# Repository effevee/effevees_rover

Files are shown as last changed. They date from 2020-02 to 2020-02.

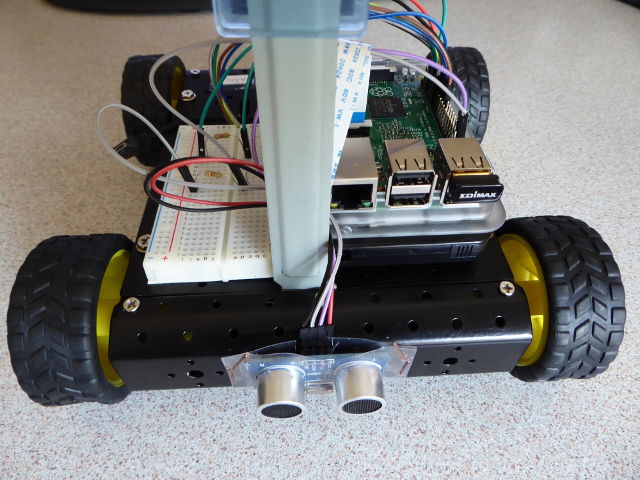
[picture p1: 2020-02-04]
documentatie/rover07.jpg

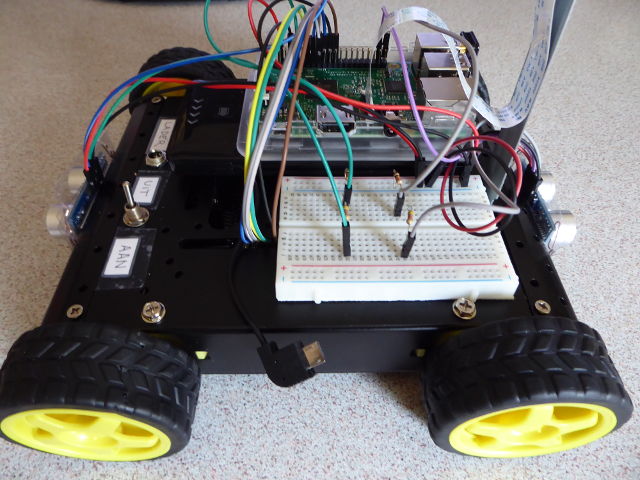
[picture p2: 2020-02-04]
documentatie/rover06.jpg

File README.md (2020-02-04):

# effevees_rover
Effevee's rover is een robotvoertuig dat op afstand bestuurd wordt en ondertussen beelden streamt van de onboard Pi camera. De aanwezige afstandssensoren zorgt ervoor dat botsingen met obstakels worden vermeden. De stuursoftware is geschreven in python en wordt bediend via een web interface. De Raspberry Pi is voorzien van een wifi module zodat we vanaf iedere pc, tablet of smartphone met een verbinding op het netwerk het voertuig draadloos kunnen besturen. In principe kan je zelfs via port forwarding op je router het voertuig besturen over het internet. Als uitbreiding
is er ook een autonavigatie modus van het robotvoertuig toegevoegd.

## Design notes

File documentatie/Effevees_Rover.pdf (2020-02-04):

# Eindproef cursus Raspberry Pi :

# Effevee's Rover

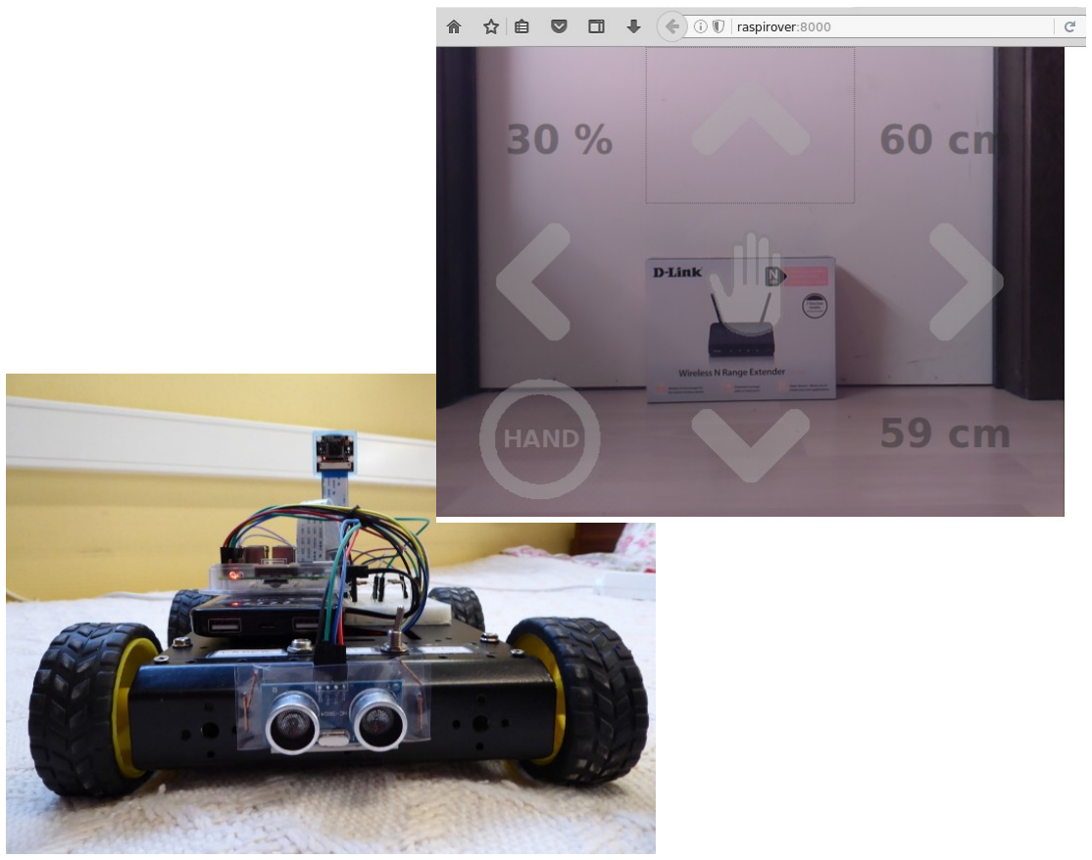
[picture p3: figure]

Alle documentatie en code van dit project kan je hier (https://drive.google.com/folderview?id=0B_sqxi1cT7K0WTJnMkV1VVNwUnM&usp=sharing) downloaden. De code is ruim voorzien van commentaar en uitleg. Mocht je nog met vragen zitten, stuur dan gerust een email naar effevee AT gmail DOT com.

Enjoy,

Effevee.

©2016 Frank Vergote | Pag 1 | Effevee's Rover

## Inhoudsopgave

©2016 Frank Vergote | Pag 2 | Effevee's Rover

## Beschrijving

Effevee's rover is een robotvoertuig dat op afstand bestuurd wordt en ondertussen beelden streamt van de onboard Pi camera. De aanwezige afstandssensoren zorgt ervoor dat botsingen met obstakels worden vermeden. De stuursoftware is geschreven in python en wordt bediend via een web interface. De Raspberry Pi is voorzien van een wifi module zodat we vanaf iedere pc, tablet of smartphone met een verbinding op het netwerk het voertuig draadloos kunnen besturen. In principe kan je zelfs via port forwarding op je router het voertuig besturen over het internet. Als uitbreiding is er ook een autonavigatie modus van het robotvoertuig toegevoegd.

## Hardware

### Controller

- Raspberry Pi 2 (http://www.conrad.be/ce/nl/product/1316978/Raspberry-Pi-2-model-B-1-GB-zonder-besturingssysteem) | 44,99 €
- EW-7811Un Edimax Wifi usb module (http://www.conrad.be/ce/nl/product/993655/Raspberry-Pi-WiFi-stick-EDIMAX-EW-7811Un?queryFromSuggest=true) | 9,79 €
- Pi (http://www.sainsmart.com/raspberry-noir-pi-camera-module-board-5mp-webcam-video-1080p-720p.html) NoIR (http://www.sainsmart.com/raspberry-noir-pi-camera-module-board-5mp-webcam-video-1080p-720p.html)camera module (http://www.sainsmart.com/raspberry-noir-pi-camera-module-board-5mp-webcam-video-1080p-720p.html) | 26,73 $
- Medion MD84610 powerbank 5V | 14,99 €

### Robotvoertuig

- 4 (http://www.sainsmart.com/sainsmart-4wd-drive-aluminum-mobile-robot-platform-for-robot-arduino-uno-mega2560-r3-duemilanove-black.html) wiel voertuig (http://www.sainsmart.com/sainsmart-4wd-drive-aluminum-mobile-robot-platform-for-robot-arduino-uno-mega2560-r3-duemilanove-black.html) chassis (http://www.sainsmart.com/sainsmart-4wd-drive-aluminum-mobile-robot-platform-for-robot-arduino-uno-mega2560-r3-duemilanove-black.html) met (http://www.sainsmart.com/sainsmart-4wd-drive-aluminum-mobile-robot-platform-for-robot-arduino-uno-mega2560-r3-duemilanove-black.html)4 gelijkstroommotoren (http://www.sainsmart.com/sainsmart-4wd-drive-aluminum-mobile-robot-platform-for-robot-arduino-uno-mega2560-r3-duemilanove-black.html) | 37,99 $
- motorstuurmodule L298N (http://www.sainsmart.com/sainsmart-l298n-dual-h-bridge-stepper-motor-driver-controller-board-module-for-arduino-robot.html) | 6,88 $
- NiMH 9,6V 1300mAh accupack (http://www.conrad.be/ce/nl/product/206632/NiMH-accupack-96-V-1300-mAh-Conrad-energy-Block-Mini-Tamiya-bus) | 27,99 €
- Voltcraft snellader (http://www.conrad.be/ce/nl/product/237851/VOLTCRAFT-230-V-snellader-1-2-A-voor-NiCd-NiMH-accupacks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) | 24,99 €
- afstandssensor (http://www.sainsmart.com/ultrasonic-ranging-detector-mod-hc-sr04-distance-sensor.html) en (http://www.sainsmart.com/ultrasonic-ranging-detector-mod-hc-sr04-distance-sensor.html) HC-SR04 (http://www.sainsmart.com/ultrasonic-ranging-detector-mod-hc-sr04-distance-sensor.html) | 2x 3,70 $
- klein breadboard (https://www.sossolutions.be/breadbordje-formaat-middel-400-gats) | 7,95 €

### Allerlei

- Digitale multimeter
- Top Craft Soldeerboutset en soldeertin | 9,99 €
- K (http://www.conrad.be/ce/nl/product/068511/Velleman-KMOW-Draad-1-x-020-mm-1-set?queryFromSuggest=true)ableerdraad 0,2 mm² (http://www.conrad.be/ce/nl/product/068511/Velleman-KMOW-Draad-1-x-020-mm-1-set?queryFromSuggest=true) | 9,99 €
- J (http://www.sainsmart.com/40pcs-dupont-wire-jumpercables-21cm-2-54mm-female-to-female-for-arduino.html)umperkabels (http://www.sainsmart.com/40pcs-dupont-wire-jumpercables-21cm-2-54mm-female-to-female-for-arduino.html) v/v en m/v | 2x 1,84 $
- V (http://www.conrad.be/ce/nl/product/419956/TOOLCRAFT-Klittenband-om-vast-te-plakken-Haak-en-lusdeel-Extra-sterk-l-x-b-1000-mm-x-50-mm-Zwart-1-rollen)elcro (http://www.conrad.be/ce/nl/product/419956/TOOLCRAFT-Klittenband-om-vast-te-plakken-Haak-en-lusdeel-Extra-sterk-l-x-b-1000-mm-x-50-mm-Zwart-1-rollen) en/of Tesa bevestigingsband | 3,62 €
- Afstandhouders
- Schroeven en moeren M3
©2016 Frank Vergote | Pag 3 | Effevee's Rover

## Controller

### Raspberry Pi 2

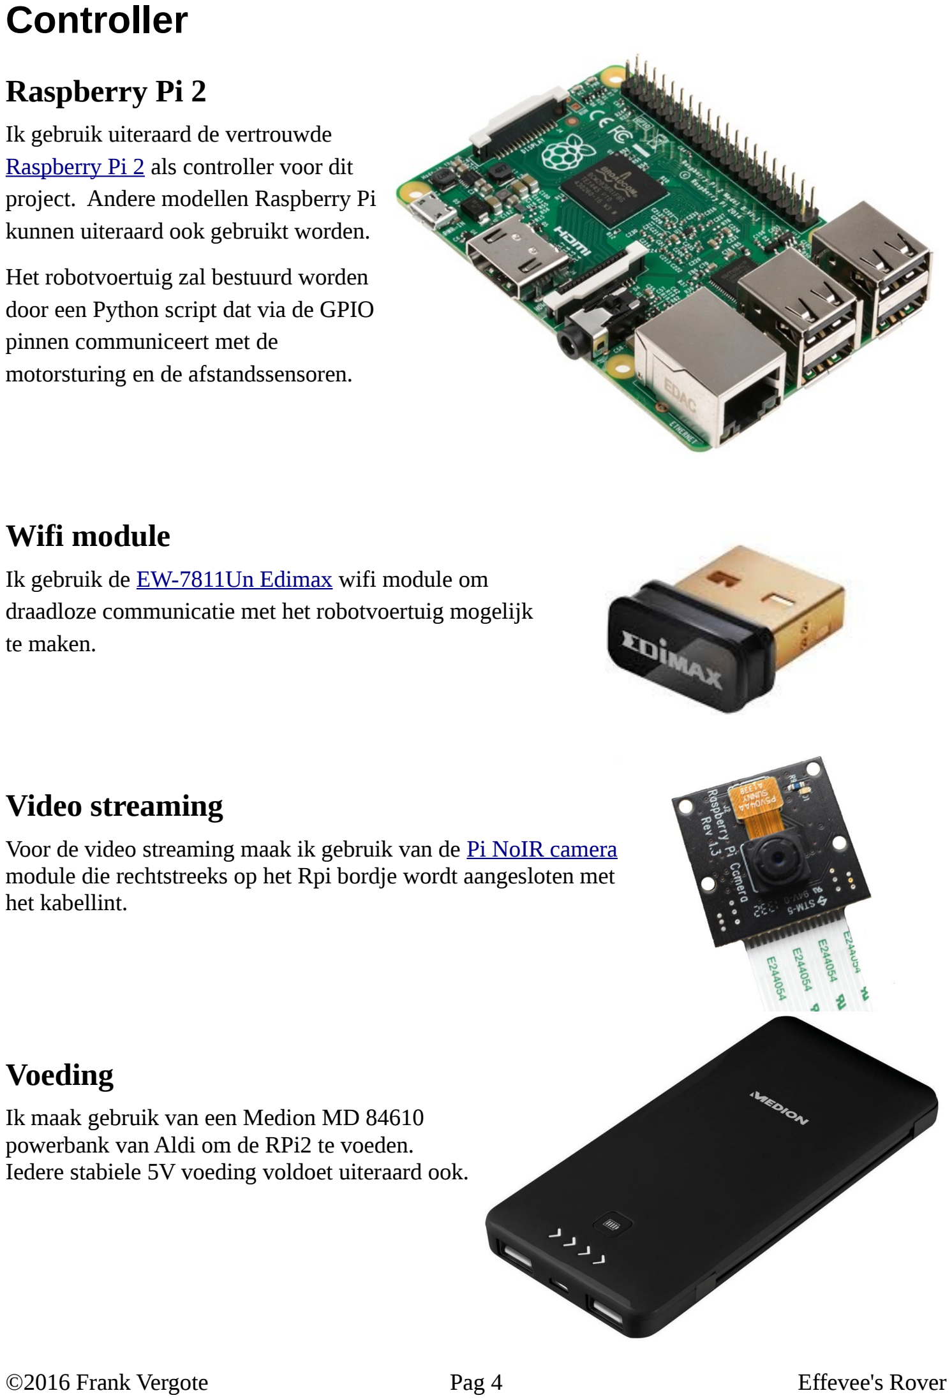
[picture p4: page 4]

Ik gebruik uiteraard de vertrouwde Raspberry Pi 2 (https://www.raspberrypi.org/products/raspberry-pi-2-model-b/) als controller voor dit project. Andere modellen Raspberry Pi kunnen uiteraard ook gebruikt worden. Het robotvoertuig zal bestuurd worden door een Python script dat via de GPIO pinnen communiceert met de motorsturing en de afstandssensoren.

### Wifi module

Ik gebruik de EW-7811Un Edimax (http://www.edimax.com/edimax/merchandise/merchandise_detail/data/edimax/global/wireless_adapters_n150/ew-7811un) wifi module om draadloze communicatie met het robotvoertuig mogelijk te maken.

### Video streaming

Voor de video streaming maak ik gebruik van de Pi NoIR camera (https://www.raspberrypi.org/products/pi-noir-camera/) module die rechtstreeks op het Rpi bordje wordt aangesloten met het kabellint.

### Voeding

Ik maak gebruik van een Medion MD 84610 powerbank van Aldi om de RPi2 te voeden. Iedere stabiele 5V voeding voldoet uiteraard ook.

©2016 Frank Vergote | Pag 4 | Effevee's Rover

## Robotvoertuig

### 4 wiel voertuig chassis

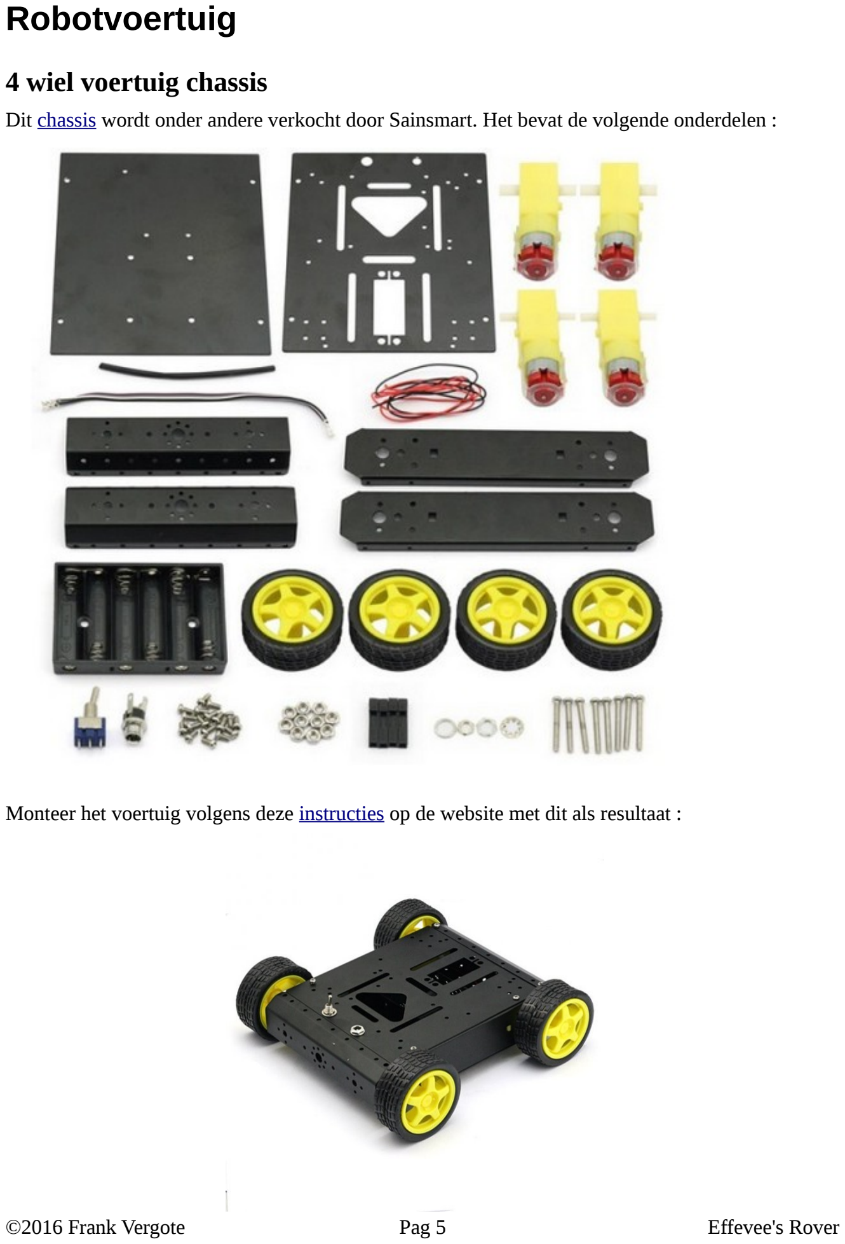
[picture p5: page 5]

Dit chassis (http://www.sainsmart.com/sainsmart-4wd-drive-aluminum-mobile-robot-platform-for-robot-arduino-uno-mega2560-r3-duemilanove-black.html) wordt onder andere verkocht door Sainsmart. Het bevat de volgende onderdelen :

Monteer het voertuig volgens deze instructies (http://www.sainsmart.com/zen/documents/20-011-922/4WD.pdf) op de website met dit als resultaat :

©2016 Frank Vergote | Pag 5 | Effevee's Rover

### Motorsturing

Stuurmodule L298N
Deze module wordt onder andere verkocht door Sainsmart. (http://www.sainsmart.com/sainsmart-l298n-dual-h-bridge-stepper-motor-driver-controller-board-module-for-arduino-robot.html)

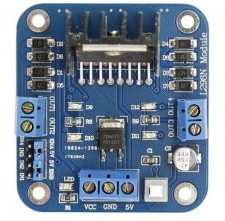
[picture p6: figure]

De L298N (gemonteerd op de grote koelvin) is een zogenaamde H-bridge. Die worden veel gebruikt om motoren aan te sturen.

Deze module kan dienen voor zowel het sturen van 2 stappenmotoren (servomotoren) als van 2 gewone DC motoren. In dit project worden de linker- en rechter DC motoren parallel geschakeld op de module.

Voor het aansturen van een stappenmotor moet de jumper over de enable pin en de 5V pin geplaatst worden.

Voor het aansturen van een DC motor kan je een PWM signaal op de enable pin plaatsen om de draaisnelheid van de motoren aan te passen.

De draairichting van de motoren wordt bepaald door de signalen die op de In aansluitingen staan. De combinatie LAAG – HOOG laat de motor vooruit draaien; de combinatie HOOG – LAAG achteruit; de combinatie LAAG – LAAG stopt de motor.

Wanneer een externe voeding (>5V) is aangesloten op VCC, dan kan je met de 5V aansluiting op de module de Raspberry Pi voeden. Uit praktijktesten is echter gebleken dat deze voeding niet stabiel genoeg is en willekeurige reboots van de Rpi veroorzaakt. We voorzien dus een aparte voeding (Medion Powerbank) voor onze Pi.

L298N aansluitingen

Pin L298N | Functie
Out1 | Motor A aansluiting +
Out2 | Motor A aansluiting -
Out3 | Motor B aansluiting +
Out4 | Motor B aansluiting -
VCC | Voedingsspanning (5V – 35V)
GND | Massa
5V | 5V output als VCC reeds spanning heeft > 5V (niet betrouwbaar)
EnA | Motor A : met jumper = stappenmotor – zonder = DC motor snelheid via PWM
EnB | Motor B : met jumper = stappenmotor – zonder = DC motor snelheid via PWM
In1, In2 | Motor A draairichting : vooruit = LAAG-HOOG / achteruit = HOOG-LAAG
In3, In4 | Motor B draairichting : vooruit = LAAG-HOOG / achteruit = HOOG-LAAG
©2016 Frank Vergote | Pag 6 | Effevee's Rover

### Voeding

Accupack
De voeding die ik voor de aandrijving van de rover gebruik is een 9,6V/1300 mAh NiMH accupack (http://www.conrad.be/ce/nl/product/206632/NiMH-accupack-96-V-1300-mAh-Conrad-energy-Block-Mini-Tamiya-bus/SHOP_AREA_20058) die je onder andere bij Conrad kan aanschaffen.
Deze voor gemonteerde accupack bestaat uit 8 NiMH cellen met een vermogen van 1300 mAh en een spanning van 9,6V. Het geheel is gemonteerd met een mini Tamiya stekker aansluiting.

Snellader

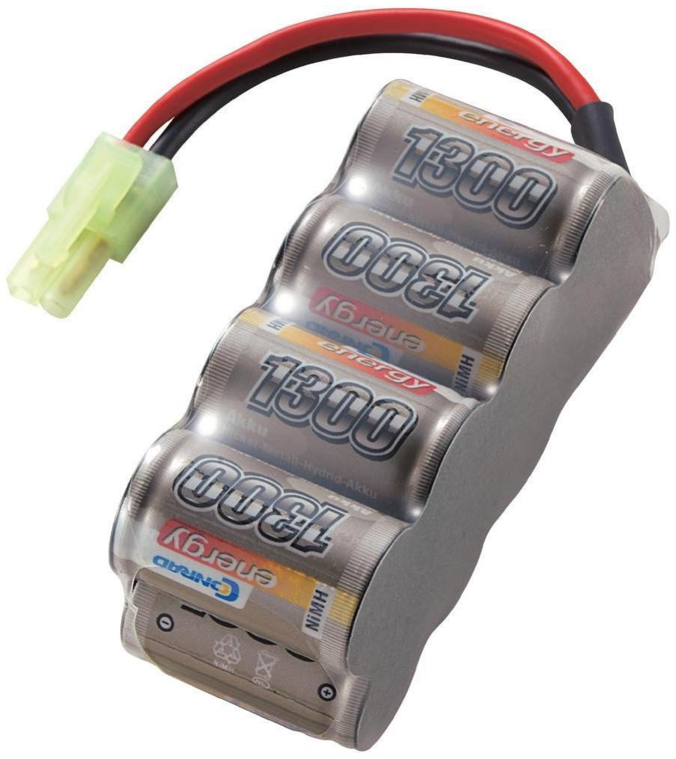
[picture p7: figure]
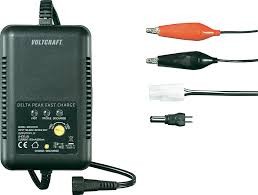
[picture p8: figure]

Ik heb er ook een Volcraft 230V snellader (http://www.conrad.be/ce/nl/product/237851/VOLTCRAFT-230-V-snellader-1-2-A-voor-NiCd-NiMH-accupacks/SHOP_AREA_21100) bijgekocht. Deze is geschikt voor NiCd en NiMH accupacks van 5 tot 8 cellen met een maximum vermogen tot 4300 mAh en heeft een instelbare laadstroom van 1A of 2A.
Dit is de ideale snellader voor racingpacks met Tamiya-stekkers. De betrouwbare Delta-V-uitschakeling garandeert een maximum lading zonder dat de accu wordt overladen. De laadtoestand wordt mbv 3 LED's aangegeven.

### Afstandssensoren

Afstandssensor HC-SR04
De HC-SR04 (http://www.sainsmart.com/ultrasonic-ranging-detector-mod-hc-sr04-distance-sensor.html) kan je onder andere kopen bij Sainsmart.
De sensor werkt volgens hetzelfde principe als de sonar van een duikboot. De sensor heeft een bereik van 2 tot 400 cm.
De Trigger pin wordt gedurende minstens 10 µs
hoog gezet. Hierdoor worden 8 ultrasone
geluidsignalen van 40 kHz uitgezonden vanaf de

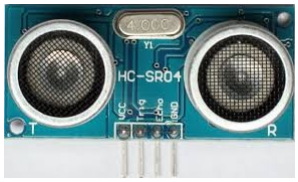
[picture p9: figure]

linker sensor (T van Transmit) die werkt als een mini luidspreker. De geluidsignalen worden door obstakels gedeeltelijk teruggekaatst en opgevangen door de rechter sensor (R van Recieve). Hierdoor wordt de Echo pin een tijd hoog evenredig met de afstand tot het obstakel. Geluidsignalen hebben een snelheid van 340 m/s in lucht. De tijd dat de echo puls hoog is, is equivalent met 2 x de afstand tot het obstakel. De formule om de afstand te berekenen wordt dus : Afstand (in cm) = Snelheid (34000 cm/s) x Echo tijd (in s) / 2

©2016 Frank Vergote | Pag 7 | Effevee's Rover

HC-SR04 aansluitingen

Pin HC-SR04 | Functie
VCC | Voeding +5V
Trigger | Output
Echo | Input
GND | Voeding -

### Robotvoertuig

Schakeling
We verbinden de verschillende onderdelen als volgt met elkaar :
Van | Jumper | Naar
Onderdeel | Pin | kleur | Onderdeel | GPIO | Fysiek#
L298N stuurmodule | OUT1 | zwart | Motoren links | | -
| OUT2 | geel/rood | | | +
| OUT3 | groen/blauw | Motoren rechts | | +
| OUT4 | zwart | | | -
| VCC | rood | Accu 9,6V | | +
| GND | zwart | | | -
| | zwart | Breadboard -
| IN1 | groen | RPi2 | 17 | 11
| IN2 | geel | | 18 | 12
| IN3 | wit | | 22 | 15
| IN4 | grijs | | 23 | 16
| ENA | blauw | | 24 | 18
| ENB | bruin | | 25 | 22
Breadboard | - zwart | | RPi2 | GND | 6
| + | rood | | 5V | 2
HC-SR04 Voor | VCC | rood | Breadboard +
| Trig | blauw | RPi2 | 27 | 13
| Echo [°] | groen | | 4 | 7
| GND | zwart | Breadboard -
HC-SR04 Achter | VCC | rood | Breadboard +
| Trig | purper | RPi2 | 20 | 38
| Echo[°] | grijs | | 21 | 40
| GND | zwart | Breadboard -
©2016 Frank Vergote | Pag 8 | Effevee's Rover

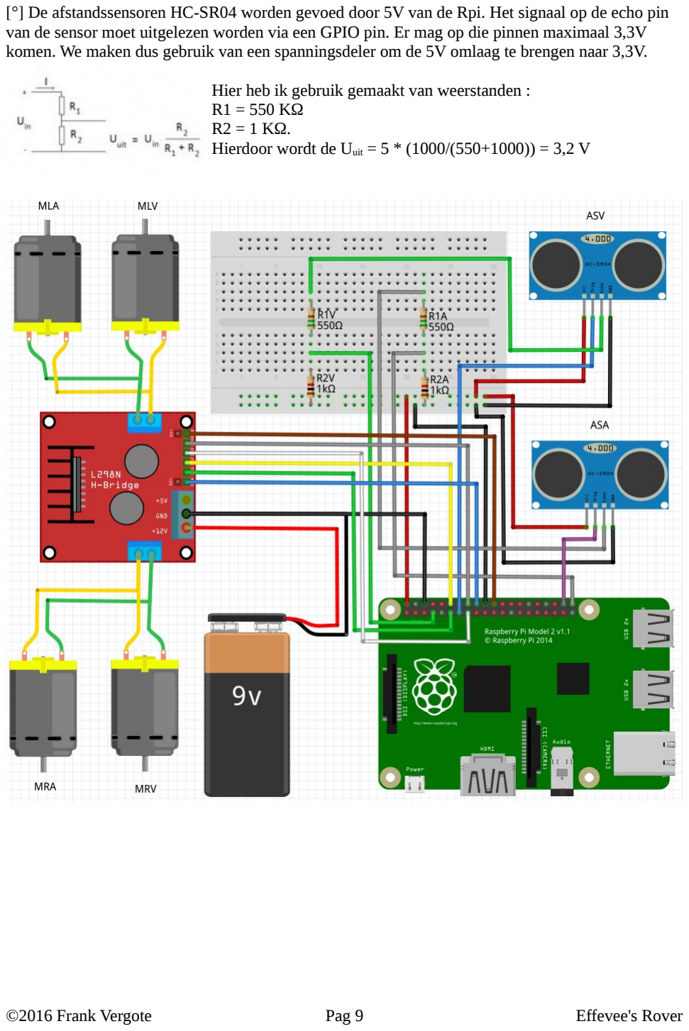
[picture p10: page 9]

[°] De afstandssensoren HC-SR04 worden gevoed door 5V van de Rpi. Het signaal op de echo pin van de sensor moet uitgelezen worden via een GPIO pin. Er mag op die pinnen maximaal 3,3V komen. We maken dus gebruik van een spanningsdeler om de 5V omlaag te brengen naar 3,3V.

Hier heb ik gebruik gemaakt van weerstanden :
R1 = 550 KΩ
R2 = 1 KΩ.
Hierdoor wordt de Uuit = 5 * (1000/(550+1000)) = 3,2 V
©2016 Frank Vergote | Pag 9 | Effevee's Rover

Montage

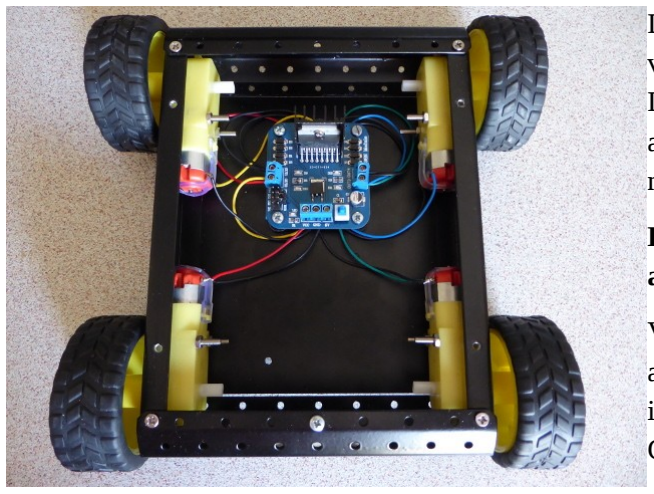
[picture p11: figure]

De L298N stuurmodule is op de onderplaat van het robotvoertuig chassis gemonteerd. De linker motoren zijn verbonden met de aansluitingen OUT1 en OUT2; de rechter motoren met OUT3 en OUT4.
Let op met de polariteit van de aansluitingen !
Verbind 6 jumper kabels met de andere aansluitingen van de L298N. Die verbind ik straks doorheen de bovenplaat met de GPIO pinnen van de Rpi.

De aan/uit schakelaar en de connector voor

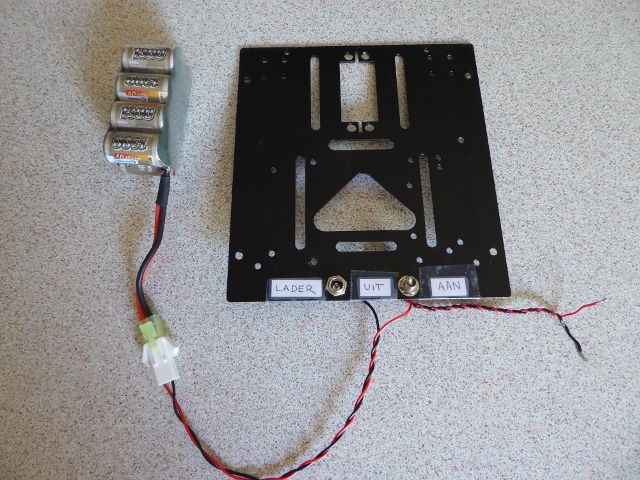
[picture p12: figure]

de lader zijn in de bovenplaat gemonteerd. Sluit de rode kabel aan op VCC en de zwarte op GND van de L298N stuurmodule.
Sluit ook een zwarte jumper kabel aan op GND . Die verbind ik straks met GND op de Rpi om een gesloten kring te maken. Sluit de Tamiya stekker aan op de accupack en bevestig deze met velcro in het chassis.

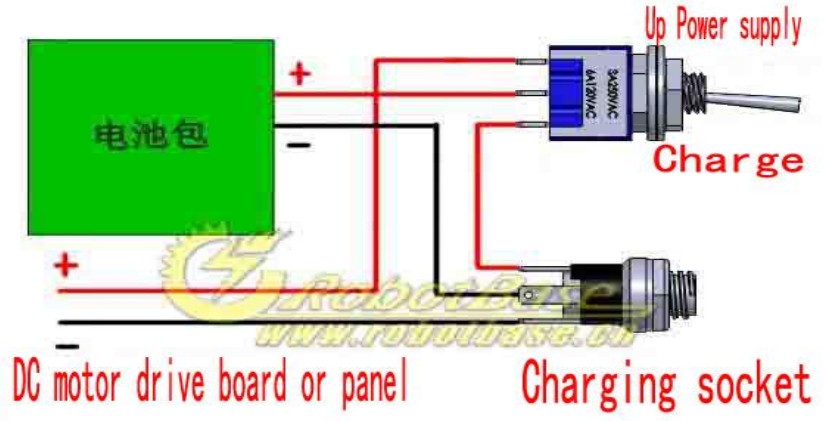
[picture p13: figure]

Dit is het bedradingsschema voor de verbinding van accupack, aan/uit schakelaar, oplaadconnector en L298N stuurmodule.
Test alles grondig na met je digitale multimeter vooraleer je de accupack en de stuurmodule aansluit.
©2016 Frank Vergote | Pag 10 | Effevee's Rover

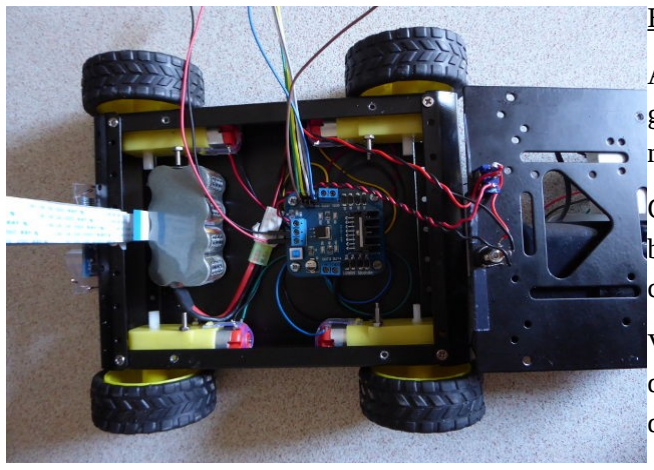
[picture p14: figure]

Binnenzicht :
Alle aansluitingen met de L298N zijn gemaakt en de jumper kabels voor de motorsturing zijn geplaatst.
Geleid de jumper kabels doorheen de bovenplaat en schroef deze vast op het chassis.
Verbind de jumper kabels van de L298N en de HC-SR04 sensoren met de Rpi volgens de schakeling tabel.

Vooraanzicht :

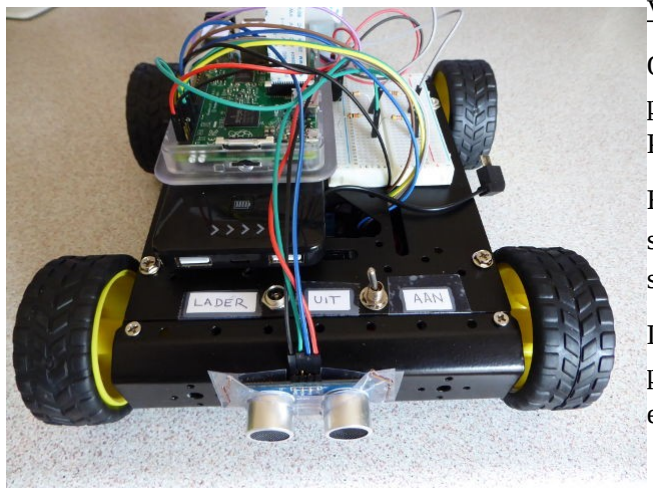
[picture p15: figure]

Op de bovenplaat heb ik links de Medion powerbank met daar bovenop de Raspberry Pi bevestigd.
Rechts is een klein breadboard voor de spanningsdelers van de HC-SR04 afstand sensoren.
De HC-SR04 heb ik met een stuk harde plastic en Tesa band bevestigd op de voor-en achterzijde van de chassis.

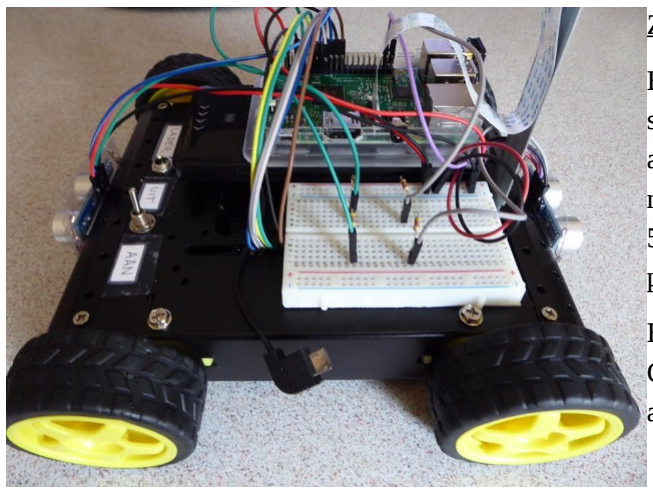
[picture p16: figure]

Zijaanzicht :
Hier zie je beter het breadboard met de spanningsdelers van de voorste en achterste afstand sensoren. De spanningsdelers zijn nodig omdat de HC-SR04 enkel werken op 5V en de Rpi maximaal 3,3V op zijn gpio pinnen mag krijgen.
Bemerk ook de lint connector van de Pi Camera die rechtstreeks op de Rpi is aangesloten.
©2016 Frank Vergote | Pag 11 | Effevee's Rover

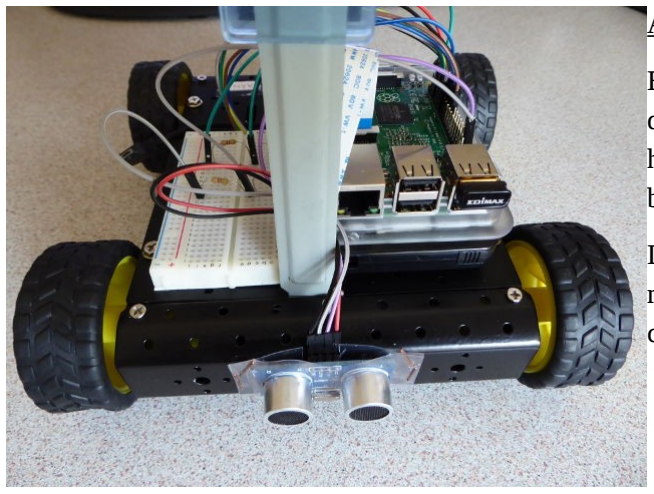
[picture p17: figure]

Achteraanzicht :
Bemerk rechts de Rpi met zijn Edimax usb draadloze wifi module. In het midden de houder voor de Pi Camera en links het breadbord met de spanningsdelers.
De achterste HC-SR04 is op dezelfde manier bevestigd op de achterzijde van het chassis.
©2016 Frank Vergote | Pag 12 | Effevee's Rover

## Software

Effevee's rover project draait op een Raspberry Pi met alleen open source software. (https://nl.wikipedia.org/wiki/Open_source)

### Operating systeem

Raspbian
Voor dit project gebruik ik Raspbian. (https://www.raspbian.org/FrontPage) Dit is een Debian Linux Wheezy gebaseerd operating systeem dat
speciaal is aangepast voor de
Raspberry Pi hardware.

Het is echter meer dan een operating systeem : het bevat meer dan 35.000 gecompileerde software componenten voor elke denkbare toepassing zodat installatie van software zeer gebruiksvriendelijk is.
Raspian is niet gebonden aan de Raspberry Pi Foundation. (https://en.wikipedia.org/wiki/Raspberry_Pi_Foundation) Het is gemaakt door een klein team van ontwikkelaars die de Raspberry Pi hardware, het Debian Linux project en de educatieve doeleinden van de de Raspberry Pi Foundation genegen zijn.
Voor het installeren van Raspbian op het SD kaartje verwijs ik naar de installatie instructies (https://www.raspberrypi.org/documentation/installation/) op de website van Raspberry Pi.

Configuratie
We starten de configuratie op met : $ sudo raspi-config
Aanpassingen :
- Expand Filesystem
- Internationalisation Options – Timezone & Keyboard
- Change User Password
- Enable Camera (!)
- Advanced Options – Hostname
- Advanced Options – Memory Split – 128 (nodig voor streaming !)
- Advanced Options – SSH aanzetten

Daarna rebooten.

©2016 Frank Vergote | Pag 13 | Effevee's Rover

### Video streaming server

UV4L
Voor dit project maak ik gebruik van UV4L die bestaat uit een aantal performante drivers voor diversen types camera (waaronder de Pi camera) en een krachtige streaming server.
Het is vooral van belang dat er tijdens het streamen niet te veel vertraging optreedt zodat de rover betrouwbaar kan bestuurd worden vanop afstand.
Voer de installatie op deze webpagina (http://www.linux-projects.org/modules/sections/index.php?op=viewarticle&artid=14) uit. Vergeet niet uv4l-webrtc te installeren. Surf na de installatie naar http://<naam van je rpi>:8080

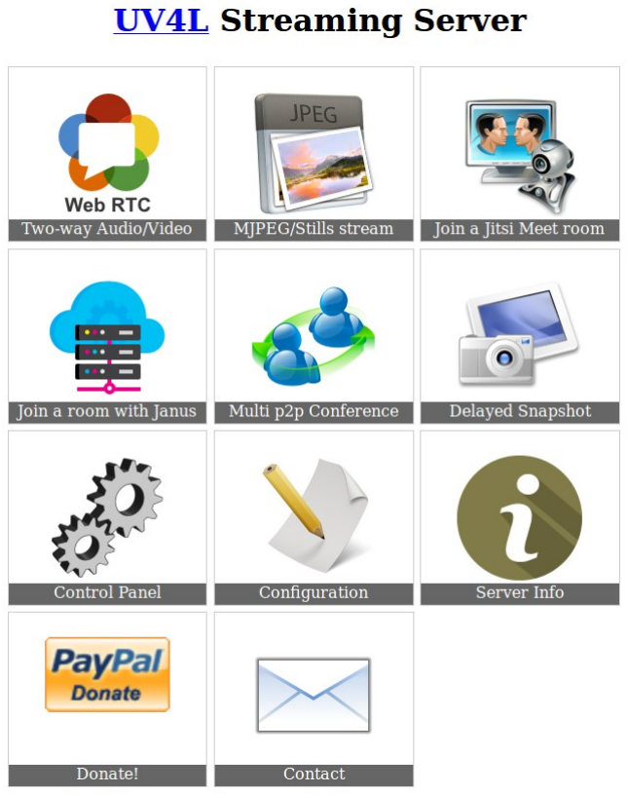
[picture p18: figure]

©2016 Frank Vergote | Pag 14 | Effevee's Rover

Van hieruit kan je onder andere :
- de video stream afbeelden (http://<naam van je rpi>:8080/stream)
- het control panel oproepen (http://<naam van je rpi>:8080/panel)
- het configuratie bestand aanpassen (http://<naam van je rpi>:8080/config)
- een snapshot nemen (http://<naam van je rpi>:8080/stream/snapshot.jpeg?delay_s=0)
- de server info tonen (http://<naam van je rpi>:8080/info)
Configuratie
Als je bovenstaande installatie uitgevoerd hebt, dan is er een default configuratie bestand voor de Raspicam mee geïnstalleerd. We gaan de resolutie aanpassen naar 640x480 om die beter geschikt te maken voor de web interface op een default smartphone.

$ sudo nano /etc/uv4l/uv4l-raspicam.conf

We passen de width en height lijnen in dit configuratie bestand aan en slaan de wijzigingen op.

# raspicam driver options

encoding = mjpeg
width = 640
height = 480
framerate = 30

Daarna herstarten we de service met :

$ sudo service uv4l_raspicam restart

We krijgen deze output waarin we de gebruikte driver en onze aangepaste resolutie zien :

<notice> [core] Trying driver 'raspicam' from built-in drivers...
<warning> [core] Driver 'raspicam' not found
<notice> [core] Trying driver 'raspicam' from external plug-in's...
<notice> [driver] Dual Raspicam Video4Linux2 Driver v1.9.35 built Mar 14 2016 <notice> [driver] Selected format: 640x480, encoding: mjpeg, JPEG Video Capture <notice> [driver] Framerate max. 30 fps
<notice> [driver] ROI: 0, 0, 1, 1
<notice> [core] Device detected!
<notice> [core] Registering device node /dev/video0

We testen tenslotte de aanpassing in onze browser :

http://<naam van je rpi>:8080/stream

©2016 Frank Vergote | Pag 15 | Effevee's Rover

### Programmeertaal

Python
Python is ontwikkeld door Guido van Rossum, destijds verbonden aan het Centrum voor Wiskunde en Informatica (https://nl.wikipedia.org/wiki/Centrum_voor_Wiskunde_en_Informatica) in Amsterdam. Het heeft zijn naam te danken aan zijn favoriete televisieprogramma : Monty Python's Flying Circus. (https://nl.wikipedia.org/wiki/Monty_Python's_Flying_Circus)
Python is ontwikkeld met het oog op leesbare code. Hieruit
vloeit haar "zuivere" stijl voort. Met weinig woorden kan men

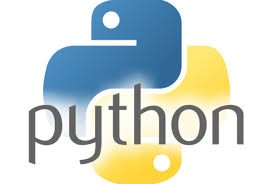
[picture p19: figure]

veel zeggen. Dit uit zich op verschillende manieren. Structuur wordt aangebracht door indentatie, of regelinspringing in plaats van bijvoorbeeld accolades uit C achtige talen. Statements (vergelijkbaar met zinnen uit gewone taal) worden simpelweg beëindigd door het eind van de regel. Variabelen krijgen geen typedeclaratie. Python maakt gebruik van duck-typing.
Een Python-programma wordt geschreven in een of meerdere tekstbestanden met de extensie .py die vervolgens uitgevoerd worden door de Python interpreter, die ze on the fly omzet naar uitvoerbare code.
Python wordt geleverd met een uitgebreide bibliotheek om van alles en nog wat standaard te kunnen bewerken. Het is erg eenvoudig om in Python herbruikbare code te schrijven. Doordat veel van de bibliotheken die mensen schrijven gratis aan anderen ter beschikking wordt gesteld, groeien de mogelijkheden van de bibliotheek voortdurend. Python wordt zo tot een programmeertaal die voor razendsnel ontwikkelen van een nieuwe applicatie kan worden gebruikt, zonder dat de daarbij geproduceerde code onleesbaar wordt.
©2016 Frank Vergote | Pag 16 | Effevee's Rover

### Web interface

WebIOPi

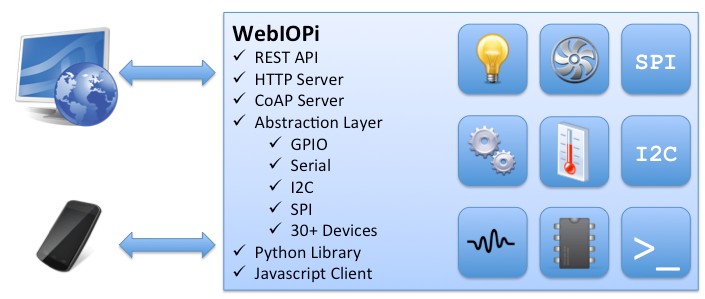
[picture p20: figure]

Voor het maken van de web interface die communiceert met de Raspberry Pi van de rover heb ik gebruik gemaakt van WebIOPi (http://webiopi.trouch.com/) – The Raspberry Pi Internet of Things Framework. Op de homepage vind je alle documentatie en tutorials terug om je te laten starten met dit interessante framework.

Deze software wordt op de Rpi geïnstalleerd en maakt het experimenteren met de GPIO pins een stuk handiger. Zie hierboven voor de belangrijkste onderdelen van deze software. Voor het ontwerp van de web UI zijn er een aantal voorgeprogrammeerde javascript instructies die het werk heel wat vereenvoudigen.
Installatie
Haal de laatste versie op van de website en pak deze uit in je Downloads folder.

$ cd Downloads
$ wget http://sourceforge.net/projects/webiopi/files/WebIOPi-0.7.1.tar.gz
$ tar xvzf WebIOPi-0.7.1.tar.gz

Opgelet : deze versie is enkel geschikt voor de originele Raspberry Pi met 26 header gpio pins. Voor de Raspberry Pi 2 is er een patch beschikbaar.

$ wget https://raw.githubusercontent.com/doublebind/raspi/master/webiopi-pi2bplus.patch
$ patch -p1 -i webiopi-pi2bplus.patch

We gaan vervolgens verder met de installatie. Deze compileert de (aangepaste) source code en installeert ze.

$ sudo ./setup.sh

Na deze installatie testen we of alles werkt. We starten eerst de service.

©2016 Frank Vergote | Pag 17 | Effevee's Rover

$ sudo service webiopi start

Vervolgens surfen we naar http://<naam van je Rpi>:8000
en loggen in met de default user webiopi en paswoord raspberry

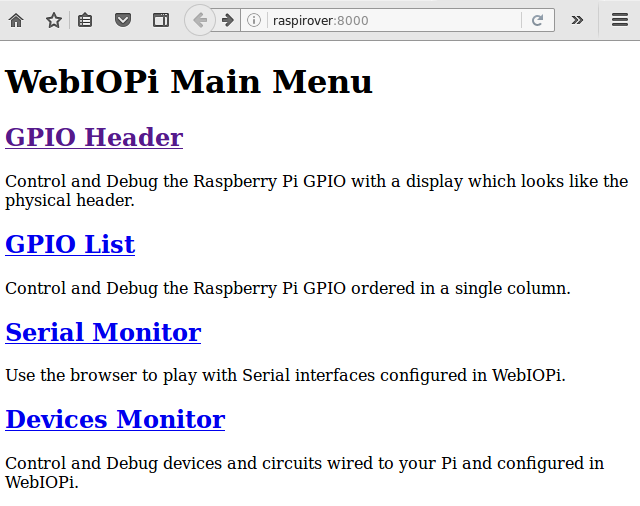
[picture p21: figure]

We komen terecht op het hoofdmenu. Click op de link GPIO Header.

©2016 Frank Vergote | Pag 18 | Effevee's Rover

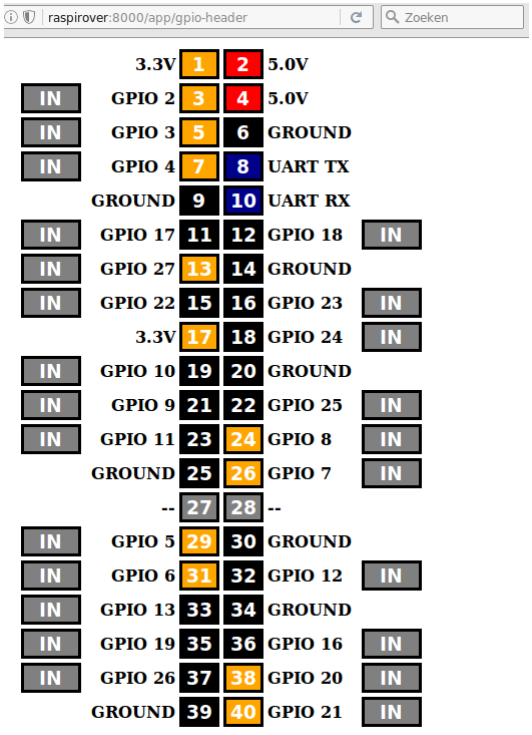
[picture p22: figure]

Je ziet de GPIO header pinnen. In het midden de fysieke pin nummers met daarnaast de GPIO naam en daarnaast het functie label of de pin IN (input) of OUT (output) is.

Door te klikken op dit functie label verwissel je tussen IN en OUT. Het signaal op de poort zelf zet je aan of af door op de fysieke pin nummer te klikken (oranje is aan, zwart is af)

Dit is een prima manier om interactief (zonder programma) je schakeling te testen.

©2016 Frank Vergote | Pag 19 | Effevee's Rover

Voor de veiligheid verander je best de default login en paswoord met :

$ sudo webiopi-passwd
WebIOPi passwd file generator
Enter Login: <nieuwe login>
Enter Password: <nieuw paswoord>
Confirm password: <nieuw paswoord>

Hash: e70c940a189251e9cd4515b3a1a6c6f02aa05c744a456ce360fe14bf2c5c0353 Saved to /etc/webiopi/passwd

Python
WebIOPi maakt gebruik van een eigen GPIO bibliotheek die met de software mee geïnstalleerd is. Deze is iets anders dan de WiringPi bibliotheek die we in de les gezien hebben maar komt op hetzelfde neer.
De werking van WebIOPi lijkt sterk op de Arduino programma's (sketches). Er zijn een aantal vaste functies beschikbaar :
1. setup() : deze functie wordt slechts éénmaal opgeroepen tijdens de starten van de WebIOPi service; ideaal dus om de gpio pinnen initialisatie te doen.
2. loop() : deze functie wordt voortdurend uitgevoerd als een oneindige lus zolang de WebIOPi service draait.. Zet hierin de functionaliteit van je script die steeds moet uitgevoerd worden.
3. destroy() : deze functie wordt aangeroepen tijdens het afsluiten van de WebIOPi service; ideaal om opruimingscode in te plaatsen.
De functies die je wil aanroepen in de web interface laat je vooraf gaan door de marker @webiopi.macro.

HTML
De Javascript bibliotheek van WebIOPi bevat volgende interessante functies :
Javascript functie | Uitleg
webiopi() | Maak een WebIOPi instance.
ready(callback) | Voer functie callback uit bij WebIOPi klaar.
setFunction(gpio,func[,callback]) | Zet gpio poort op (in|out|pwm) en roep callback op (optioneel).
digitalWrite(gpio,value[,callback]) | Zet waarde (0|1) op gpio poort en roep callback op (optioneel).
digitalRead(gpio[,callback]) | Lees waarde van gpio poort en roep callback op (optioneel).
toggleValue(gpio) | Wissel de waarde van de gpio poort.
©2016 Frank Vergote | Pag 20 | Effevee's Rover

Javascript functie | Uitleg
callMacro(macro [,args [,callback]]) | Roep macro op van server met optioneel argumenten en callback functie.
outputSequence(gpio,period,sequence [,callback]) | Output sequence met periode (ms) naar gpio poort en roep callback op (optioneel).
pulse(gpio [,callback]) | Output een puls naar gpio poort en roep callback op (optioneel).
pulseRatio(gpio, ratio [,callback]) | Output PWM duty cycle ratio naar gpio poort en roep callback op (optioneel)
pulseAngle(gpio, angle [,callback]) | Output PWM angle naar gpio poort en roep callback op (optioneel).
createButton(id, label [,mousedown [,mouseup]]) | Maak een gewone knop. Je kan functies voor mousedown en mouseup event optioneel meegeven.
createFunctionButton(gpio) | Maak een knop op de functie van de gpio poort te wisselen.
createGPIOButton(gpio,label) | Maak een knop die bij iedere klik de waarde van de gpio poort wisselt.
createMacroButton(id, label, marcro, args) | Maak een knop die een macro oproept op de server met argumenten.
createSequenceButton(id, label, gpio, period, sequence) | Maak een knop die sequence met periode (ms) stuurt naar gpio poort.
createRatioSlider(gpio, ratio) | Maak een slider die een PWM duty cucle ratio stuurt naar de gpio poort.
createAngleSlider(gpio, angel) | Maal een slider die een PWM angle stuurt naar de gpio poort (servomotoren).
setLabel(id, label) | Verandert het label van de knop.

Voor het maken van de rover web interface heb ik vooral gebruik gemaakt van de createMacroButton functie waarmee functies worden opgeroepen in mijn Python script.

Configuratie
Om WebIOPi te configureren om gebruik te maken van onze eigen webpagina en code voeren we het volgende uit :
$ sudo nano /etc/webiopi/config
In de sectie [SCRIPTS] voegen we een lijn toe die verwijst naar ons python script.

[SCRIPTS]
# Load custom scripts syntax :

# name = sourcefile

# each sourcefile may have setup, loop and destroy functions and macros #myscript = /home/pi/webiopi/examples/scripts/macros/script.py

myproject = /home/pi/effevees_rover/python/effevees_rover.py
©2016 Frank Vergote | Pag 21 | Effevee's Rover

In de sectie [HTTP] voegen we een lijn toe die verwijst naar de plaats van onze html pagina. Standaard wordt index.html afgebeeld.

[HTTP]
# HTTP Server configuration

enabled = true
port = 8000

# File containing sha256(base64("user:password")) # Use webiopipasswd command to generate it passwdfile = /etc/webiopi/passwd

# Change login prompt message

prompt = "WebIOPi"

# Use docroot to change default HTML and resource files location #docroot = /home/pi/webiopi/examples/scripts/macros

docroot = /home/pi/effevees_rover/templates

# Use welcomefile to change the default "Welcome" file

#welcomefile = index.html

In de sectie [REST] wijzigen we enkele lijnen die de web interface beperken tot de gebruikte gpio pinnen.

[REST]
# By default, REST API allows to GET/POST on all GPIOs

# Use gpioexport to limit GPIO available through REST API gpioexport = 17,18,22,23,24,25,27,4,20,21

# Uncomment to forbid changing GPIO values gpiopostvalue = true

# Uncomment to forbid changing GPIO functions gpiopostfunction = false

# Uncomment to disable automatic device mapping #devicemapping = false

Tenslotte zorgen we er nog voor dat de WebIOPi service automatisch start bij het booten van de Rpi. $ sudo update-rc.d webiopi defaults

©2016 Frank Vergote | Pag 22 | Effevee's Rover

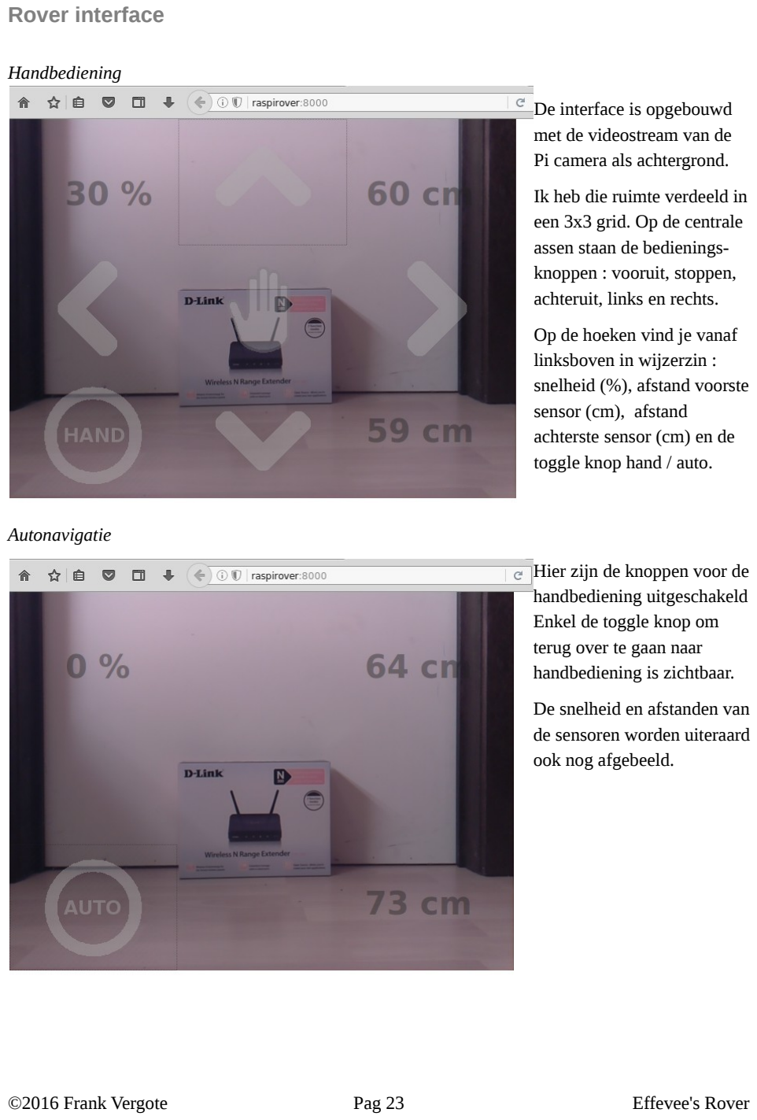
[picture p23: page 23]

Rover interface

Handbediening
De interface is opgebouwd
met de videostream van de
Pi camera als achtergrond. Ik heb die ruimte verdeeld in een 3x3 grid. Op de centrale assen staan de bedienings-knoppen : vooruit, stoppen, achteruit, links en rechts.
Op de hoeken vind je vanaf linksboven in wijzerzin :
snelheid (%), afstand voorste sensor (cm), afstand
achterste sensor (cm) en de toggle knop hand / auto.

Autonavigatie
Hier zijn de knoppen voor de handbediening uitgeschakeld Enkel de toggle knop om
terug over te gaan naar
handbediening is zichtbaar. De snelheid en afstanden van de sensoren worden uiteraard ook nog afgebeeld.
©2016 Frank Vergote | Pag 23 | Effevee's Rover

## Source code

Voor dit project werd de volgende folder structuur opgezet : /home/pi/
└── effevees_rover
├── python
│ └── effevees_rover.py
└── templates
| ├── effevees_rover.css ├── effevees_rover.js ├── index.html ├── knop-auto.png ├── knop-hand.png ├── pijl-achteruit.png ├── pijl-links.png ├── pijl-rechts.png ├── pijl-vooruit.png └── stoppen.png

### index.html

<!DOCTYPE html>
<html>
<head>
<meta httpequiv="Content-Type" content="text/html; charset=UTF-8">
<meta name="viewport" content="height=480px,width=640px userscalable=yes"> <title>Effevee's Rover</title>
<script type="text/javascript" src="/webiopi.js"></script>
<script type="text/javascript" src="/effevees_rover.js"></script>
<link rel="stylesheet" type="text/css" href="/effevees_rover.css"> </head>

<body>
<div id="controls">
<img src="http://raspirover.local:8080/stream/video.mjpeg" width="640" height="480">
<input type="text" id="snelheid"></br>
<input type="text" id="afstandvoor"></br>
<input type="text" id="afstandachter"></br> </div>
</body>
</html>
©2016 Frank Vergote | Pag 24 | Effevee's Rover

### effevees_rover.js

// dit wordt uitgevoerd bij de initialisatie van WebIOPi webiopi().ready(function() {

// Maak de macro knop vooruit
// bij het klikken wordt de python code Vooruit aangeroepen
var knop_vooruit = webiopi().createMacroButton("idBtnVooruit", "", "Vooruit");

// Maak de macro knop stoppen
// bij het klikken wordt de python code Stoppen aangeroepen
var knop_stoppen = webiopi().createMacroButton("idBtnStoppen", "", "Stoppen");

// Maak de macro knop achteruit
// bij het klikken wordt de python code Achteruit aangeroepen
var knop_achteruit = webiopi().createMacroButton("idBtnAchteruit", "", "Achteruit");

// Maak de macro knop links
// bij het klikken wordt de python code Links aangeroepen
var knop_links = webiopi().createMacroButton("idBtnLinks", "", "Links");

// Maak de macro knop rechts
// bij het klikken wordt de python code Rechts aangeroepen
var knop_rechts = webiopi().createMacroButton("idBtnRechts", "", "Rechts");

// Maak de knop hand/auto
// bij het klikken wordt de python code ToggleModus aangeroepen
// de callback functie updateModus update de class van de knop
var knop_modus = webiopi().createButton("idBtnModus", "", function() { webiopi().callMacro("ToggleModus", [], updateModus);
});

// Voeg de knoppen toe aan het HTML element met ID="controls" mbv jQuery $("#controls").append(knop_vooruit); $("#controls").append(knop_stoppen); $("#controls").append(knop_achteruit); $("#controls").append(knop_links); $("#controls").append(knop_rechts); $("#controls").append(knop_modus);

// Start een timer om iedere seconde de UI te updaten setInterval(LeesWaarden,1000);

});

// deze functie roept de python code WaardenUI aan om de waarden voor de UI op te halen
// de callback functie updateUI zorgt voor de eigenlijke update van de UI function LeesWaarden(){
webiopi().callMacro("WaardenUI", [], updateUI);
}

// deze functie wordt opgeroepen als callback van LeesWaarden (timer)
// de returnwaarden worden gebruikt om de UI te updaten met de nieuwe waarden
©2016 Frank Vergote | Pag 25 | Effevee's Rover

var updateUI = function(macro, args, response) {
// returnwaarden zijn als tekst doorgegeven gescheiden door ";" var waarden = response.split(";"); $("#snelheid").val(waarden[0]+" %"); $("#afstandvoor").val(waarden[1]+" cm"); $("#afstandachter").val(waarden[2]+" cm"); $("#automodus").val(waarden[3]);
};

// deze functie wordt opgeroepen bij de toggle van hand naar auto of omgekeerd // de returnwaarde wordt gebruikt om de class van de besturingsknoppen aan te passen
// waardoor we via css de juiste knop kunnen afbeelden in de UI
var updateModus = function(macro, args, response) {
var waarden = response.split(";");
// update class voor knoppen
if (waarden[3] == "True") { document.getElementById("idBtnVooruit").className = "auto"; document.getElementById("idBtnStoppen").className = "auto"; document.getElementById("idBtnAchteruit").className = "auto"; document.getElementById("idBtnLinks").className = "auto"; document.getElementById("idBtnRechts").className = "auto"; document.getElementById("idBtnModus").className = "auto";
} else {
document.getElementById("idBtnVooruit").className = "hand"; document.getElementById("idBtnStoppen").className = "hand"; document.getElementById("idBtnAchteruit").className = "hand"; document.getElementById("idBtnLinks").className = "hand"; document.getElementById("idBtnRechts").className = "hand"; document.getElementById("idBtnModus").className = "hand";
}
}
©2016 Frank Vergote | Pag 26 | Effevee's Rover

### effevees_rover.css

/* controle paneel */
#controls {

position:absolute;
top:0px;
left:0px;
width:640px;
height:480px;
border:0px solid #000000;
}

/* knop vooruit */
#idBtnVooruit {

position:absolute;
top:0px;
left:214px;
width:213px;
height:160px;
opacity:0.4;
zindex: 20;
background: url(pijlvooruit.png) norepeat; backgroundposition: center center; border:0px solid #000000;
}

/* knop stoppen */
#idBtnStoppen {

position:absolute;
top:160px;
left:214px;
width:213px;
height:160px;
opacity:0.4;
zindex: 20;
background: url(stoppen.png) norepeat; backgroundposition: center center; border:0px solid #000000;
}

/* knop achteruit */
#idBtnAchteruit {

position:absolute;
top:320px;
left:214px;
width:213px;
height:160px;
opacity:0.4;
zindex: 20;
background: url(pijlachteruit.png) norepeat; backgroundposition: center center; border:0px solid #000000;
}

/* knop links */
#idBtnLinks {

position:absolute;
©2016 Frank Vergote | Pag 27 | Effevee's Rover

top:160px;
left:0px;
width:213px;
height:160px;
opacity:0.4;
zindex: 20;
background: url(pijllinks.png) norepeat; backgroundposition: center center; border:0px solid #000000;
}

/* knop rechts */
#idBtnRechts {

position:absolute;
top:160px;
left:426px;
width:213px;
height:160px;
opacity:0.4;
zindex: 20;
background: url(pijlrechts.png) norepeat; backgroundposition: center center; border:0px solid #000000;
}

/* toggle modus handbediening */ #idBtnModus.Default,
#idBtnModus.hand {

position:absolute;
top:320px;
left:0px;
width:213px;
height:160px;
opacity:0.4;
zindex: 20;
background: url(knophand.png) norepeat; backgroundposition: center center; border:0px solid #000000;
}

/* toggle modus auto navigatie */ #idBtnModus.auto {
position:absolute;
top:320px;
left:0px;
width:213px;
height:160px;
opacity:0.4;
zindex: 20;
background: url(knopauto.png) norepeat; backgroundposition: center center; border:0px solid #000000;
}

/* knoppen minder transparant maken bij hover */ #idBtnVooruit:hover,
#idBtnStoppen:hover,

#idBtnAchteruit:hover,

©2016 Frank Vergote | Pag 28 | Effevee's Rover

#idBtnLinks:hover,

#idBtnRechts:hover,

#idBtnModus:hover {

opacity:0.8;
}

/* knoppen verbergen bij auto navigatie */ #idBtnVooruit.auto,
#idBtnStoppen.auto,

#idBtnAchteruit.auto,

#idBtnLinks.auto,

#idBtnRechts.auto {

visibility: hidden;
}

/* text input boxen voor afbeelden snelheid en afstanden */ input[type=text] {
background: transparent;
border: none;
width: 150px;
fontsize: 40px;
fontweight: bold;
fontcolor: #afaeae;
}

/* snelheid */
#snelheid {

position: absolute;
top:70px;
left:70px;
opacity:0.4;
zindex: 20;
}

/* afstand voor */
#afstandvoor {

position: absolute;
top:70px;
left:450px;
opacity:0.4;
zindex: 20;
}

/* afstand achter */
#afstandachter {

position: absolute;
top:370px;
left:450px;
opacity:0.4;
zindex: 20;
}
©2016 Frank Vergote | Pag 29 | Effevee's Rover

### effevees_rover.py

#!/usr/bin/python

## Frank Vergote

## email effevee@gmail.com

## WebIOPi rover versie 5

## 06/05/2016

############################################################################### # Bibliotheken

import webiopi
import time
import threading
import logging
import random

# gebruik de gpio lib van WebIOPi voor de interactie met de gpio pinnen

gpio = webiopi.GPIO

############################################################################### # Constanten en variabelen ###############################################################################

# GPIO poorten voor sturen motoren via L298N motor module

# Motor | LINKS | RECHTS

# GPIO | IN1 | IN2 | IN3 | IN4

# Vooruit | low | high | low | high

# Stoppen | low | low | low | low

# Achteruit | high | low | high | low

L298N_IN1 = 17 | # richting motoren links
L298N_IN2 = 18 | # richting motoren links
L298N_ENA = 24 | # snelheid motoren links (PWM)
L298N_IN3 = 22 | # richting motoren rechts
L298N_IN4 = 23 | # richting motoren rechts
L298N_ENB = 25 | # snelheid motoren rechts (PWM)

# commando's motoren

VOORUIT = 1
STOPPEN = 2
ACHTERUIT = 3
LINKS = 4
RECHTS = 5

# snelheden motoren

minSnelheid = 0 | # alle snelheden in procenten
maxSnelheid = 100
stapSnelheid = 10
snelheid = minSnelheid
Commando = STOPPEN
laatsteCommando = STOPPEN
©2016 Frank Vergote | Pag 30 | Effevee's Rover

# modus besturing rover

autoModus = False | # auto navigatie boolean
autoSnelheid = 30 | # snelheid in % bij auto navigatie
kwartDraai = 2 | # tijd in sec voor een kwartdraai (90°)

# GPIO poorten afstandssensoren HC-SR04 voor en achter

ASV_TRIG = 27 | # trigger afstandssensor voor
ASV_ECHO = 4 | # echo afstandssensor voor
ASA_TRIG = 20 | # trigger afstandssensor achter
ASA_ECHO = 21 | # echo afstandssensor achter
ASV = 1 | # afstandssensor voor
ASA = 2 | # afstandssensor achter

# berekenen afstanden

PULSE = 0.00001 | # trigger pulse 10 micro sec
SNELHEID_GELUID = 34000 # geluidsnelheid in cm/sec

# afstanden

minAfstand = 50 | # minimum afstand tot obstakel in cm
maxAfstand = 200 | # maximum afstand tot obstakel in cm
afstandVoor = 200 | # variabele afstand voorste sensor
afstandAchter = 200 | # variabele afstand achterste sensor

############################################################################### # Setup wordt 1 maal uitgevoerd tijdens het starten van de WebIOPi service

# hier doen we de initialisatie van de GPIO pinnen ###############################################################################

def setup():

# Zet debug aan

#webiopi.setDebug()

# setup GPIO poorten L298N gpio.setFunction(L298N_IN1,gpio.OUT) gpio.setFunction(L298N_IN2,gpio.OUT) gpio.setFunction(L298N_ENA,gpio.PWM) gpio.setFunction(L298N_IN3,gpio.OUT) gpio.setFunction(L298N_IN4,gpio.OUT) gpio.setFunction(L298N_ENB,gpio.PWM)

# setup GPIO poorten HC-SR04 gpio.setFunction(ASV_TRIG,gpio.OUT) gpio.setFunction(ASV_ECHO,gpio.IN) gpio.setFunction(ASA_TRIG,gpio.OUT) gpio.setFunction(ASA_ECHO,gpio.IN)

# init GPIO poorten L298N

gpio.digitalWrite(L298N_IN1,gpio.LOW) gpio.digitalWrite(L298N_IN2,gpio.LOW) gpio.pwmWrite(L298N_ENA,snelheid/100)
gpio.digitalWrite(L298N_IN3,gpio.LOW)
gpio.digitalWrite(L298N_IN4,gpio.LOW)
©2016 Frank Vergote | Pag 31 | Effevee's Rover

gpio.pwmWrite(L298N_ENB,snelheid/100)

# init GPIO poorten HC-SR04 gpio.digitalWrite(ASV_TRIG,gpio.LOW) gpio.digitalWrite(ASA_TRIG,gpio.LOW)

# thread opzetten voor afstandsmetingen en botsingsdetectie thread_metingen = threading.Thread(target = MeetAfstanden) thread_metingen.setDaemon(True)

thread_metingen.start()

# thread opzetten voor auto navigatie

thread_navigatie = threading.Thread(target = Navigeer) thread_navigatie.setDaemon(True)
thread_navigatie.start()

############################################################################### # Loop wordt voortdurend herhaald zolang de WebIOPi service draait

# ik gebruik dit niet omdat loop enkel een single thread ondersteunt. ###############################################################################

# def loop():

############################################################################### # Destroy wordt uitgevoerd bij het stoppen van de WebIOPi service

# dit wordt gebruikt voor de cleanup van de GPIO poorten. ###############################################################################

def destroy():

# reset GPIO poorten

gpio.digitalWrite(L298N_IN1,gpio.LOW) gpio.digitalWrite(L298N_IN2,gpio.LOW) gpio.digitalWrite(L298N_IN3,gpio.LOW) gpio.digitalWrite(L298N_IN4,gpio.LOW) gpio.digitalWrite(ASV_TRIG,gpio.LOW) gpio.digitalWrite(ASA_TRIG,gpio.LOW)

# setup GPIO poorten

gpio.setFunction(L298N_IN1,gpio.IN) gpio.setFunction(L298N_IN2,gpio.IN) gpio.disablePWM(L298N_ENA) gpio.setFunction(L298N_IN3,gpio.IN) gpio.setFunction(L298N_IN4,gpio.IN) gpio.disablePWM(L298N_ENB) gpio.setFunction(ASV_TRIG,gpio.IN) gpio.setFunction(ASV_ECHO,gpio.IN) gpio.setFunction(ASA_TRIG,gpio.IN) gpio.setFunction(ASA_ECHO,gpio.IN)

############################################################################### # ZetSnelheid bepaalt de snelheid van de rover :

# manuele modus : verhoogt de huidige snelheid met stapSnelheid tot maxSnelheid

# | bij veranderen van richting reset de snelheid

©2016 Frank Vergote | Pag 32 | Effevee's Rover

# auto modus : gebruikt steeds een vaste snelheid > autoSnelheid ###############################################################################

def ZetSnelheid(Commando):
global snelheid, laatsteCommando

# snelheid op 0 zetten bij wijziging richting if Commando != laatsteCommando:

snelheid = 0
gpio.pwmWrite(L298N_ENA,snelheid/100) gpio.pwmWrite(L298N_ENB,snelheid/100) laatsteCommando = Commando

# instellen snelheid

if autoModus:
# auto modus > autoSnelheid

snelheid = autoSnelheid
else:
# manuele modus > snelheid verhogen met stapSnelheid snelheid += stapSnelheid

# begrenzen tot maxSnelheid

if snelheid > maxSnelheid:
snelheid = maxSnelheid

return snelheid

############################################################################### # Afstand bepaalt de afstand (cm) tot een obstakel met de HC-SR04 sensoren

# de tijd dat de echo puls hoog is evenredig met 2x de afstand tot het obstakel ###############################################################################

def Afstand(sensor):

# sensor variabelen

if sensor == ASV:
TRIG = ASV_TRIG
ECHO = ASV_ECHO
elif sensor == ASA:
TRIG = ASA_TRIG
ECHO = ASA_ECHO
else:
# ongeldige sensor

print('Ongeldige sensor!') return maxAfstand

# initialisatie

afstand = 0

# als echo nu reeds hoog is, dan ongeldige meting

if gpio.digitalRead(ECHO):
return maxAfstand

# zet trigger laag en wacht 50 msec om sensor te stabiliseren gpio.digitalWrite(TRIG, gpio.LOW)

time.sleep(0.05)
©2016 Frank Vergote | Pag 33 | Effevee's Rover

# zet trigger hoog gedurende 10 micro sec gpio.digitalWrite(TRIG,gpio.HIGH) time.sleep(PULSE)

gpio.digitalWrite(TRIG,gpio.LOW)

# initialisatie tijden

start, stop = time.time(), time.time()

# wachten op echo hoog voor maximum 20 msec

# indien langer, dan afbreken met ongeldige meting while not gpio.digitalRead(ECHO):

start = time.time()
if start stop > 0.02:
return maxAfstand

# wachten op echo laag voor maximum 20 msec

# indien langer, dan afbreken met ongeldige meting while gpio.digitalRead(ECHO):

stop = time.time()
if stop start > 0.02:
return maxAfstand

# berekenen afstand

delta = stop start
afstand = delta * SNELHEID_GELUID / 2.0

return round(afstand, 0)

############################################################################### # MeetAfstanden draait in een aparte thread. De afstanden van beide sensoren # worden iedere 250 msec gemeten en bewaard in globale variabelen.

# In manuele stuurmodus wordt de rover gestopt bij risico op botsing. ############################################################################### def MeetAfstanden():

global afstandVoor, afstandAchter

while True:

# initialiseer de lijsten voor de afstandsmetingen

av, aa = [], []

# meet 5 afstanden voor iedere sensor en voeg ze toe in de lijsten for i in range(5):

av.append(Afstand(ASV))
aa.append(Afstand(ASA))

# verwijder de minimum en maximum meetwaarden uit de lijsten av.remove(min(av))

av.remove(max(av))
aa.remove(min(aa))
aa.remove(max(aa))

# bereken het gemiddelde van de restende meetwaarden uit de lijsten afstandVoor = round(sum(av)/len(av),0)

afstandAchter = round(sum(aa)/len(aa),0)

# debug

©2016 Frank Vergote | Pag 34 | Effevee's Rover

#logging.debug("Richting: %s",laatsteCommando) #logging.debug("Afstand voor: %d cm", afstandVoor) #logging.debug("Afstand achter: %d cm", afstandAchter)

# stoppen bij risico op botsing in manuele stuurmodus

if not autoModus:
if (laatsteCommando == VOORUIT) and (afstandVoor < minAfstand): Stoppen()
if (laatsteCommando == ACHTERUIT) and (afstandAchter < minAfstand): Stoppen()

# wacht even

time.sleep(0.25)

############################################################################### # WaardenUI wordt periodiek aangeroepen vanuit javascript (setInterval).

# De waarden dienen om de UI up te daten. ###############################################################################

@webiopi.macro
def WaardenUI():

return "%d;%d;%d;%s" % (snelheid, afstandVoor, afstandAchter, autoModus)

############################################################################### # ToggleModus verandert de status van de besturingsmodus.

# wordt aangeroepen bij het klikken op de modus knop van de UI ###############################################################################

@webiopi.macro
def ToggleModus():
global autoModus

# rover stoppen

Stoppen()

# modus besturing veranderen autoModus = not autoModus

return WaardenUI()

############################################################################### # Navigeer zorgt ervoor dat de rover automatisch zijn weg zoekt.

# Dit gebeurt in een aparte thread. We moeten namelijk terug kunnen

# overschakelen naar manuele modus via de UI ###############################################################################

def Navigeer():
global snelheid

while True:

# enkel uitvoeren bij automatische navigatie while autoModus:

©2016 Frank Vergote | Pag 35 | Effevee's Rover

# rover vooruit

Vooruit()

# botsing gevaar

while afstandVoor < minAfstand:

# rover stoppen

Stoppen()

# rover 2 sec achteruit

if (afstandAchter > minAfstand): Achteruit()
time.sleep(2)
Stoppen()

# willekeurige kwartdraai

if random.randint(1,10) <= 5: Links()
else:
Rechts()

# even pauzeren

time.sleep(0.5)

############################################################################### # Rover vooruit

# wordt aangeroepen bij het klikken op de vooruit knop van de UI ###############################################################################

@webiopi.macro
def Vooruit():

# snelheid instellen

ZetSnelheid(VOORUIT)

# linkermotoren vooruit

gpio.digitalWrite(L298N_IN1,gpio.LOW) gpio.digitalWrite(L298N_IN2,gpio.HIGH)

# rechtermotoren vooruit

gpio.digitalWrite(L298N_IN3,gpio.LOW) gpio.digitalWrite(L298N_IN4,gpio.HIGH)

# snelheid linker en rechtermotoren gpio.pwmWrite(L298N_ENA,snelheid/100) gpio.pwmWrite(L298N_ENB,snelheid/100)

############################################################################### # Rover stoppen

# wordt aangeroepen bij het klikken op de stoppen knop van de UI ###############################################################################

@webiopi.macro
def Stoppen():
global snelheid
©2016 Frank Vergote | Pag 36 | Effevee's Rover

# snelheid op 0 zetten

snelheid = 0

# linkermotoren stoppen

gpio.digitalWrite(L298N_IN1,gpio.LOW) gpio.digitalWrite(L298N_IN2,gpio.LOW)

# rechtermotoren stoppen

gpio.digitalWrite(L298N_IN3,gpio.LOW) gpio.digitalWrite(L298N_IN4,gpio.LOW)

# snelheid linker en rechtermotoren gpio.pwmWrite(L298N_ENA,snelheid)

gpio.pwmWrite(L298N_ENB,snelheid)

############################################################################### # Rover achteruit

# wordt aangeroepen bij het klikken op de achteruit knop van de UI ###############################################################################

@webiopi.macro
def Achteruit():

# snelheid instellen

ZetSnelheid(ACHTERUIT)

# linkermotoren achteruit

gpio.digitalWrite(L298N_IN1,gpio.HIGH) gpio.digitalWrite(L298N_IN2,gpio.LOW)

# rechtermotoren achteruit gpio.digitalWrite(L298N_IN3,gpio.HIGH) gpio.digitalWrite(L298N_IN4,gpio.LOW)

# snelheid linker en rechtermotoren gpio.pwmWrite(L298N_ENA,snelheid/100) gpio.pwmWrite(L298N_ENB,snelheid/100)

############################################################################### # Rover links

# wordt aangeroepen bij het klikken op de links knop van de UI

# voert een kwartdraai (90°) uit; resultaat is afhankelijk van ondergrond ###############################################################################

@webiopi.macro
def Links():
global snelheid

# snelheid instellen

ZetSnelheid(LINKS)

# kwartdraai uitvoeren aan snelheid 40% snelheid = 40

# linkermotoren achteruit

gpio.digitalWrite(L298N_IN1,gpio.HIGH)
©2016 Frank Vergote | Pag 37 | Effevee's Rover

gpio.digitalWrite(L298N_IN2,gpio.LOW)

# rechtermotoren vooruit

gpio.digitalWrite(L298N_IN3,gpio.LOW) gpio.digitalWrite(L298N_IN4,gpio.HIGH)

# snelheid linker en rechtermotoren gpio.pwmWrite(L298N_ENA,snelheid/100) gpio.pwmWrite(L298N_ENB,snelheid/100)

# tijd voor kwartdraai en daarna stoppen time.sleep(kwartDraai)

Stoppen()

############################################################################### # Rover rechts

# wordt aangeroepen bij het klikken op de rechts knop van de UI

# voert een kwartdraai (90°) uit; resultaat is afhankelijk van ondergrond ###############################################################################

@webiopi.macro
def Rechts():
global snelheid

# snelheid instellen

ZetSnelheid(RECHTS)

# kwartdraai uitvoeren aan snelheid 40% snelheid = 40

# linkermotoren vooruit

gpio.digitalWrite(L298N_IN1,gpio.LOW) gpio.digitalWrite(L298N_IN2,gpio.HIGH)

# rechtermotoren achteruit gpio.digitalWrite(L298N_IN3,gpio.HIGH) gpio.digitalWrite(L298N_IN4,gpio.LOW)

# snelheid linker en rechtermotoren gpio.pwmWrite(L298N_ENA,snelheid/100) gpio.pwmWrite(L298N_ENB,snelheid/100)

# tijd voor kwartdraai en daarna stoppen time.sleep(kwartDraai)

Stoppen()
©2016 Frank Vergote | Pag 38 | Effevee's Rover

### Afbeeldingen

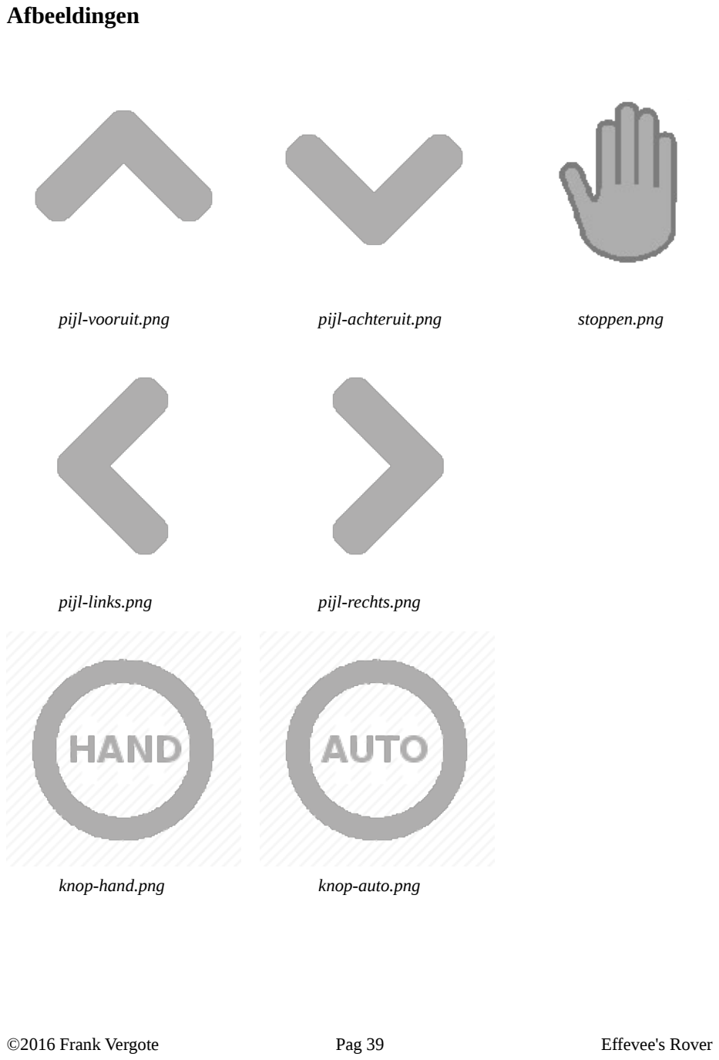
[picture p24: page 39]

pijl-vooruit.png | pijl-achteruit.png | stoppen.png
pijl-links.png | pijl-rechts.png
knop-hand.png | knop-auto.png
©2016 Frank Vergote | Pag 39 | Effevee's Rover

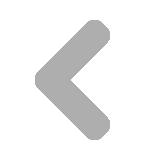
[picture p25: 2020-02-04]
templates/pijl-links.png

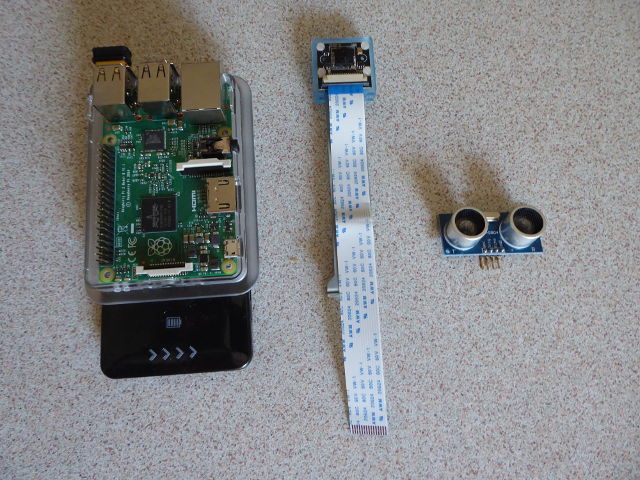
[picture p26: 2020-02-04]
documentatie/rover03.jpg

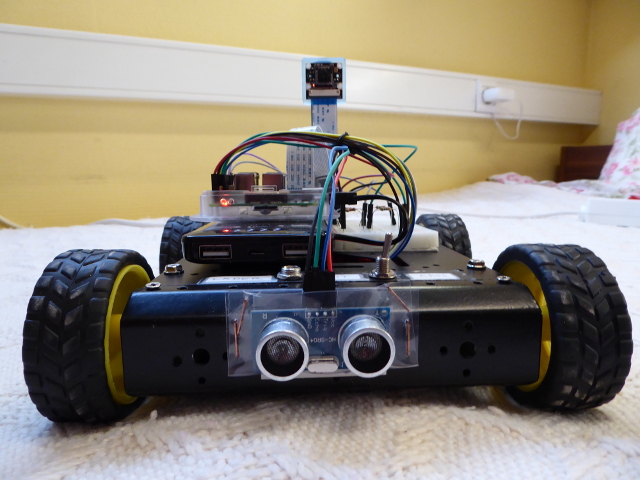
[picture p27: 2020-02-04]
documentatie/rover10.jpg

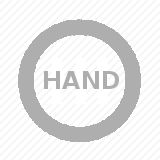
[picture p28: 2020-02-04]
templates/knop-hand.png

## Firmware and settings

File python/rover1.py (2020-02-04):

#!/usr/bin/python


# PythonCard versie


from PythonCard import model, timer

import wiringpi as wpi
import time


class Minimal(model.Background):
    global INPUT, OUTPUT, PWM
    global LOW, HIGH
    global L298N_IN1, L298N_IN2, L298N_IN3, L298N_IN4, L298N_ENA, L298N_ENB
    global ASV_TRIG, ASV_ECHO, ASA_TRIG, ASA_ECHO
    global VOORUIT, ACHTERUIT, STOPPEN, LINKS, RECHTS
    global minSnelheid, maxSnelheid, stapSnelheid, Snelheid, laatsteCommando
    global Versnellen
    global cmVoor, cmAchter, minAfstand, Afstand
    global ASV, ASA, PULSE, SNELHEID_GELUID

    # constanten
    INPUT = 0
    OUTPUT = 1
    PWM = 2
    LOW = 0
    HIGH = 1

    # GPIO poorten voor sturen motoren via L298N motor module
    # -------------------------------------------------------
    # Motor            LINKS               RECHTS
    # GPIO          IN1     IN2         IN3     IN4
    # -------------------------------------------------------
    # Vooruit       low     high        low     high
    # Stoppen       low     low         low     low
    # Achteruit     high    low         high    low
    # -------------------------------------------------------
    L298N_IN1 = 17          # richting motoren links
    L298N_IN2 = 18          # richting motoren links
    L298N_ENA = 24          # snelheid motoren links (PWM)

    L298N_IN3 = 22          # richting motoren rechts
    L298N_IN4 = 23          # richting motoren rechts
    L298N_ENB = 25          # snelheid motoren rechts (PWM)

    # commando's motoren
    VOORUIT = 1
    STOPPEN = 2
    ACHTERUIT = 3
    LINKS = 4
    RECHTS = 5

    # snelheden motoren
    minSnelheid = 0
    maxSnelheid = 100
    stapSnelheid = 10
    Snelheid = minSnelheid
    laatsteCommando = 0

    # GPIO poorten afstandssensoren HC-SR04 voor en achter
    ASV_TRIG = 27           # trigger afstandssensor voor
    ASV_ECHO = 4            # echo afstandssensor voor

    ASA_TRIG = 20           # trigger afstandssensor achter
    ASA_ECHO = 21           # echo afstandssensor achter

    PULSE = 0.00001         # trigger pulse 10 micro sec
    SNELHEID_GELUID = 34000  # geluidsnelheid in cm/s

    ASV = 1                 # afstandssensor voor
    ASA = 2                 # afstandssensor achter

    minAfstand = 30         # minimum afstand tot obstakel in cm

    def on_menuFileAbout_select(self, event):
        pass

    def on_initialize(self, event):

        # GPIO wiring conventie
        wpi.wiringPiSetupGpio()

        # setup GPIO poorten L298N en HC-SR04
        wpi.pinMode(L298N_IN1, OUTPUT)
        wpi.pinMode(L298N_IN2, OUTPUT)
        wpi.pinMode(L298N_IN3, OUTPUT)
        wpi.pinMode(L298N_IN4, OUTPUT)
        wpi.pinMode(L298N_ENA, PWM)
        wpi.pinMode(L298N_ENB, PWM)
        wpi.softPwmCreate(L298N_ENA, minSnelheid, maxSnelheid)
        wpi.softPwmCreate(L298N_ENB, minSnelheid, maxSnelheid)
        wpi.pinMode(ASV_TRIG, OUTPUT)
        wpi.pinMode(ASV_ECHO, INPUT)
        wpi.pinMode(ASA_TRIG, OUTPUT)
        wpi.pinMode(ASA_ECHO, INPUT)

        # init GPIO poorten L298N en HC-SR04
        wpi.digitalWrite(L298N_IN1, LOW)
        wpi.digitalWrite(L298N_IN2, LOW)
        wpi.digitalWrite(L298N_IN3, LOW)
        wpi.digitalWrite(L298N_IN4, LOW)
        wpi.softPwmWrite(L298N_ENA, Snelheid)
        wpi.softPwmWrite(L298N_ENB, Snelheid)
        wpi.digitalWrite(ASV_TRIG, LOW)
        wpi.digitalWrite(ASA_TRIG, LOW)

        # setup timer voor afstandsmetingen
        self.mijnTimer = timer.Timer(self.components.STVoor, -1)
        self.mijnTimer.Start(500)

    def Versnellen(Commando):
        global Snelheid, maxSnelheid, stapSnelheid, laatsteCommando

        # Snelheid op 0 zetten bij wijziging commando
        if Commando != laatsteCommando:
            Snelheid = 0
            wpi.softPwmWrite(L298N_ENA, Snelheid)
            wpi.softPwmWrite(L298N_ENB, Snelheid)
            laatsteCommando = Commando

        # snelheid verhogen met stapSnelheid
        Snelheid += stapSnelheid

        # begrenzen tot maxSnelheid
        if Snelheid > maxSnelheid:
            Snelheid = maxSnelheid

        return Snelheid

    def on_BtnVooruit_mouseClick(self, event):
        global Snelheid

        # Snelheid verhogen met stapSnelheid
        Versnellen(VOORUIT)

        # Snelheid tonen in GaugeSnelheid
        self.components.GaugeSnelheid.value = Snelheid

        # linkermotoren vooruit
        wpi.digitalWrite(L298N_IN1, LOW)
        wpi.digitalWrite(L298N_IN2, HIGH)

        # rechtermotoren vooruit
        wpi.digitalWrite(L298N_IN3, LOW)
        wpi.digitalWrite(L298N_IN4, HIGH)

        # snelheid linker- en rechtermotoren
        wpi.softPwmWrite(L298N_ENA, Snelheid)
        wpi.softPwmWrite(L298N_ENB, Snelheid)

    def on_BtnStoppen_mouseClick(self, event):
        global Snelheid

        # Snelheid op 0 zetten
        Snelheid = 0

        # Snelheid tonen in GaugeSnelheid
        self.components.GaugeSnelheid.value = Snelheid

        # linkermotoren stoppen
        wpi.digitalWrite(L298N_IN1, LOW)
        wpi.digitalWrite(L298N_IN2, LOW)

        # rechtermotoren stoppen
        wpi.digitalWrite(L298N_IN3, LOW)
        wpi.digitalWrite(L298N_IN4, LOW)

        # snelheid linker- en rechtermotoren
        wpi.softPwmWrite(L298N_ENA, Snelheid)
        wpi.softPwmWrite(L298N_ENB, Snelheid)

    def on_BtnAchteruit_mouseClick(self, event):
        global Snelheid

        # Snelheid verhogen met stapSnelheid
        Versnellen(ACHTERUIT)

        # Snelheid tonen in GaugeSnelheid
        self.components.GaugeSnelheid.value = Snelheid

        # linkermotoren achteruit
        wpi.digitalWrite(L298N_IN1, HIGH)
        wpi.digitalWrite(L298N_IN2, LOW)

        # rechtermotoren achteruit
        wpi.digitalWrite(L298N_IN3, HIGH)
        wpi.digitalWrite(L298N_IN4, LOW)

        # snelheid linker- en rechtermotoren
        wpi.softPwmWrite(L298N_ENA, Snelheid)
        wpi.softPwmWrite(L298N_ENB, Snelheid)

    def on_BtnLinks_mouseClick(self, event):
        global Snelheid

        # Snelheid verhogen met stapSnelheid
        Versnellen(LINKS)

        # Snelheid tonen in GaugeSnelheid
        self.components.GaugeSnelheid.value = Snelheid

        # linkermotoren achteruit
        wpi.digitalWrite(L298N_IN1, HIGH)
        wpi.digitalWrite(L298N_IN2, LOW)

        # rechtermotoren vooruit
        wpi.digitalWrite(L298N_IN3, LOW)
        wpi.digitalWrite(L298N_IN4, HIGH)

        # snelheid linker- en rechtermotoren
        wpi.softPwmWrite(L298N_ENA, Snelheid)
        wpi.softPwmWrite(L298N_ENB, Snelheid)

    def on_BtnRechts_mouseClick(self, event):
        global Snelheid

        # Snelheid verhogen met stapSnelheid
        Versnellen(RECHTS)

        # Snelheid tonen in GaugeSnelheid
        self.components.GaugeSnelheid.value = Snelheid

        # linkermotoren vooruit
        wpi.digitalWrite(L298N_IN1, LOW)
        wpi.digitalWrite(L298N_IN2, HIGH)

        # rechtermotoren achteruit
        wpi.digitalWrite(L298N_IN3, HIGH)
        wpi.digitalWrite(L298N_IN4, LOW)

        # snelheid linker- en rechtermotoren
        wpi.softPwmWrite(L298N_ENA, Snelheid)
        wpi.softPwmWrite(L298N_ENB, Snelheid)

    def Afstand(sensor):

        # sensor variabelen
        if sensor == ASV:
            TRIG = ASV_TRIG
            ECHO = ASV_ECHO
        elif sensor == ASA:
            TRIG = ASA_TRIG
            ECHO = ASA_ECHO
        else:
            print('Ongeldige sensor!')
            afstand = minAfstand
            return afstand

        # trigger hoog zetten gedurende 10 micro sec
        wpi.digitalWrite(TRIG, HIGH)
        time.sleep(PULSE)
        wpi.digitalWrite(TRIG, LOW)

        # wachten op echo hoog
        while wpi.digitalRead(ECHO) == LOW:
            start = time.time()

        # wachten op echo laag
        while wpi.digitalRead(ECHO) == HIGH:
            stop = time.time()

        # berekenen afstand
        delta = stop - start
        afstand = delta * SNELHEID_GELUID / 2.0

        return round(afstand, 1)

    def on_STVoor_timer(self, event):
        global Snelheid, cmVoor, cmAchter, minAfstand

        # meet afstand voor en achter
        cmVoor = Afstand(ASV)
        cmAchter = Afstand(ASA)

        # toon afstanden
        self.components.STVoor.text = str(cmVoor) + ' cm'
        self.components.STAchter.text = str(cmAchter) + ' cm'

        # kontrole afstanden
        if (cmVoor <= minAfstand) or (cmAchter <= minAfstand):
            Snelheid = 0
            wpi.softPwmWrite(L298N_ENA, Snelheid)
            wpi.softPwmWrite(L298N_ENB, Snelheid)

    def on_close(self, event):

        # setup GPIO poorten
        wpi.pinMode(L298N_IN1, INPUT)
        wpi.pinMode(L298N_IN2, INPUT)
        wpi.pinMode(L298N_IN3, INPUT)
        wpi.pinMode(L298N_IN4, INPUT)
        wpi.pinMode(L298N_ENA, INPUT)
        wpi.pinMode(L298N_ENB, INPUT)
        wpi.pinMode(ASV_TRIG, INPUT)
        wpi.pinMode(ASV_ECHO, INPUT)
        wpi.pinMode(ASA_TRIG, INPUT)
        wpi.pinMode(ASA_ECHO, INPUT)

        # reset GPIO poorten
        wpi.digitalWrite(L298N_IN1, LOW)
        wpi.digitalWrite(L298N_IN2, LOW)
        wpi.digitalWrite(L298N_IN3, LOW)
        wpi.digitalWrite(L298N_IN4, LOW)
        wpi.digitalWrite(L298N_ENA, LOW)
        wpi.digitalWrite(L298N_ENB, LOW)
        wpi.digitalWrite(ASV_TRIG, LOW)
        wpi.digitalWrite(ASV_ECHO, LOW)
        wpi.digitalWrite(ASA_TRIG, LOW)
        wpi.digitalWrite(ASA_ECHO, LOW)
        self.Destroy()


if __name__ == '__main__':
    app = model.Application(Minimal)
    app.MainLoop()

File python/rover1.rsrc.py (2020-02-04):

{'application':{'type':'Application',
          'name':'Template',
    'backgrounds': [
    {'type':'Background',
          'name':'bgTemplate',
          'title':u'Rover1',
          'size':(292, 224),
          'style':['resizeable'],

        'menubar': {'type':'MenuBar',
         'menus': [
             {'type':'Menu',
             'name':'menuFile',
             'label':'&File',
             'items': [
                  {'type':'MenuItem',
                   'name':'menuFileExit',
                   'label':'E&xit',
                   'command':'exit',
                  },
              ]
             },
         ]
     },
         'components': [

{'type':'StaticText', 
    'name':'STAchter', 
    'position':(20, 145), 
    'backgroundColor':(237, 236, 235, 255), 
    'text':u'Achter', 
    },

{'type':'StaticText', 
    'name':'STVoor', 
    'position':(20, 65), 
    'backgroundColor':(237, 236, 235, 255), 
    'text':u'Voor ', 
    },

{'type':'Gauge', 
    'name':'GaugeSnelheid', 
    'position':(95, 20), 
    'size':(100, 28), 
    'backgroundColor':(191, 191, 191, 255), 
    'foregroundColor':(30, 144, 255, 255), 
    'layout':u'horizontal', 
    'max':100, 
    'value':0, 
    },

{'type':'Button', 
    'name':'BtnRechts', 
    'position':(190, 100), 
    'label':u'Rechts', 
    },

{'type':'Button', 
    'name':'BtnLinks', 
    'position':(10, 100), 
    'label':u'Links', 
    },

{'type':'Button', 
    'name':'BtnAchteruit', 
    'position':(100, 140), 
    'label':u'Achteruit', 
    },

{'type':'Button', 
    'name':'BtnStoppen', 
    'position':(100, 100), 
    'label':u'Stoppen', 
    },

{'type':'Button', 
    'name':'BtnVooruit', 
    'position':(100, 60), 
    'label':u'Vooruit', 
    },

] # end components
} # end background
] # end backgrounds
} }
